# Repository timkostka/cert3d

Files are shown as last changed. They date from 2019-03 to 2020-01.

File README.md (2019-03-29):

# cert3d

Is your 3d printer firmware certified?

# What is Cert3D?

Cert3D is a project designed to certify the performance of 3d printer firmware.  It works by sending test g-code to the printer and monitoring the output of stepper motors.

## Why is Cert3D?

Within the 3d printer firmware community, there is a lack of verification of software features.  A massive amount of man-hours is spent on tracking down bugs which could otherwise be detected automatically.  The aim of this project is to enable developers to ensure features are working as intended before releasing software.

## Who benefits?

For developers, the testing framework helps identify bugs quickly allowing them to be fixed quickly.  The improved software quality due to this benefits.

## How does it work?

There are two parts to Cert3D--A hardware module and a software program.

### The hardware module

The hardware module is hooked up to the 3d printer board and monitors status of the stepper motors and other peripherals.

### The software program

The software sends runs a series of tests by sending g-code to the 3d printer board.  During these tests, it also reads back information from the hardware module.  It analyses these results to ensure the printer is working as intended.

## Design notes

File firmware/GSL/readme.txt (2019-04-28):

The GSL are Generic STM32F4 Libraries for various peripherals.  This is an
additional abstraction layer that makes use of the STM32 HAL libraries in a
way that is hopefully easier and more straightforward to use.

The GSL are header-only C++ libraries.  To use them, simply include the
"gsl_includes.h" file from a C++ source file.

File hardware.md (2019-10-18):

# Cert3D Hardware module

This file is for laying out the requirements for the hardware module.

At high speed, we need to monitor the DIR and STEP lines on each stepper motor driver.

Number of stepper motors:

* X axis

* Y axis

* Z axis

* E (extruder) axis

* (maybe) E2 axis (second extruder)

In each motor takes 4 lines (2 lines with rising/falling for each).  If we use timers on the STM32F4, what does this look like?

With 2 DMAs with 8 streams each, we are limited to 16 DMA-based interrupt transfers.  This would be enough without E2, except that doesn't leave us any for other functions, such as a UART debug stream.

Another option would be to set triggers to both rising and falling, and then detect the state in an interrupt or something.  This is more prone to error, but would probably work.

Another option would be to eliminate DMA-based triggers and do it in software via interrupts.

## What timing is necessary?

Looking at the DRV8825 driver, the required timing on a pulse on the STEP or DIR lines is 1.9us.  There is also a 650ns setup time between DIR rising/falling and STEP rising.  It would be nice to be able to verify that timing.

With an STM32F4 clock speed of 180MHz, we can run some timers at 180 MHz, and some others at 90MHz.  At 90MHz, this gives a timer period of 11.1 ns.  That seems good enough.

## Plan forward

Two timer channels per extruder seems fine, with one hooked up to STEP and the other to DIR.  If we plan for a single extruder, this is a total of 8 timer channels, and 8 DMA streams.

Can we use only high speed (APB2) timers for these?  These are TIM1 and TIM8-11.  Yes, both TIM1 and TIM8 have 4 available input channels.  Actually, the DMA streams overlap, so this would only allow us 6 DMA requests.  Let's just set it up with TIM1 only for now and work out the details later.  We may have to use 6 channels on high speed timers and 2 channels on slower timers.

### Results

I managed to get this working just fine using the TIM1 timer in IC mode for two channels at once.  Easily extensible to 4.  Resoltion of 1 timer tick at 160 MHz.  The output is written via DMA to a circular buffer.  I can easily parse this to capture individual edges.

What resolution should results be stored as?  If i use uint32_t and a tick of 180 MHz, this will overflow around 24sec.  So I could use uint64_t instead, although it's a bit clunky.  If I convert to float, then I lose some resolution.

Another option is to output only the delta between pulses.  I could use a uint16_t, and use 0 to indicate that there was no change for 2^16 ticks.  That is way more memory efficient.  2^16 ticks at 180MHz is 0.4ms, which is a bit low.  So maybe use uint32_t to reduce the number of zeros.

### Plotting results

Results should be output in a variety of modes.  One of those should be an oscilloscope-type mode where edges are shown.  This may be fun to develop.

## Hardware pins

What is actually needed to monitor/simulate a 3d printer board?

* (8 high-speed pins, 4 slower pins) Monitor X, Y, Z, and E stepper motors
  * Per motor, need STEP and DIR hooked up to timer IC inputs.  Can monitor EN with a slower GPIO pin.
* (1 pin) Stepper motor monitoring
* (3 pins) X, Y, and Z end-stops
* (2 pins) SWD interface
* (2 pins) UART debug input/output
* (1 pin) Error-indicating LED
* (1 pin) monitor bed heating on/off
* (3 pins) monitor fans?
* (2 DAC pins) simulate bed and hot end thermistors
* (1 pin) monitor hot end heater on/off
* (1 pin) simulate EZABL type bed leveler

### How to simulate a thermistor?

The common thermistors used in 3D printers are 100kOhm at room temp and go lower than this as they heat up, becoming as low as 220 Ohm at 150C.

A 100kOhm digital potentiometer might work well.

On the board (Duet 2 Wifi), thermistors are connected in the following circuit:

```
                         [3.3V]
                           |
                     [4.7kOhm 0.1%]
                           | 
MCU PIN>---+---[100kOhm]---+---[THERMISTOR]---+
           |                                 |
           = [2.2uF]                         |
           |                                 |
          GND                               GND
```

So the voltage on the thermistor shouldn't go over 2.24V.  If shorted, the current through it will be 0.7mA.

There are a few issues with using digipots for this.  First, the tolerance is awful, typically 20-30% and quite nonlinear.  Second, the number of taps is limited.  With 256 taps, the resistance increment would be 39 Ohm.  This is the difference between 225C and 265C.

One option would be using two digipots in series to get better resolution.  If we had a 100kOhm and a 1kOhm in series.  But 1kOhm are expensive.  No good solution that I can see.

For the bed, a digipot is probably fine.

I could use a DAC.  The STM32F4 has a 12-bit DAC.  This gives a resolution of 0.8 mV.  This is way better.  This may vary depending on how boards are set up, but it's doable.

With 2 DACs, we can simualte 2 thermistors.

### STEP/DIR channels

What channels and DMA streams can we use for the STEP/DIR signal monitoring?

* TIM1_CH1 - DMA2 Stream 1

* TIM1_CH2 - DMA2 Stream 2

* TIM1_CH3 - DMA2 Stream 6

* TIM1_CH4 - DMA2 Stream 4

* TIM8_CH1 - DMA2 Stream 2

* TIM8_CH2 - DMA2 Stream 3

* TIM8_CH3 - DMA2 Stream 4

* TIM8_CH4 - DMA2 Stream 7

So out of these, we can have 6 enabled.  These can monitor X, Y and E.  All channel on TIM1 and channels 2 and 4 on TIM8.

We need 2 more slow speed channels to monitor Z.

* TIM3_CH1 - DMA1 Stream 4

* TIM3_CH2 - DMA1 Stream 5

### Timer triggering

We need to start all timers at the same time in order to get relative timing correct between channels.  We can do this by setting up TIM3 and TIM8 in slave mode that trigger off of TIM1_TRGO signal.  For TIM3, this is the ITR0 trigger per Table 98 in RM90.  For TIM8, this is also ITRO0 per Table 94.

We want all timers to be in sync so that CNT register values are identical between them.  We can do this by triggering them to start at the same time.  I set up TIM1 in master mode and had TIM3 and TIM8 trigger off of it.  Doing this, there was a delay of 18-20 ticks between TIM1 and TIM8.  In other words, `TIM1->CNT = TIM8->CNT + (18 to 20)`.  This isn't desirable.

Can I use a different timer to trigger TIM1, TIM3 and TIM8 all at the same time?  The delay between the trigger and the timer starting should be the same for all three.

* TIM1 can be triggered from TIM5 (ITR0), TIM2 (ITR1), TIM3 (ITR2), and TIM4 (ITR3)
* TIM3 can be triggered from TIM1 (ITR0), TIM2 (ITR1), TIM5 (ITR2), and TIM4 (ITR3)
* TIM8 can be triggered from TIM1 (ITR0), TIM2 (ITR1), TIM4 (ITR2), and TIM5 (ITR3)

So yes, we can use TIM2 to trigger the other three.  Conveniently, they all use the same ITR1 signal to do so.  I did this and the timers appear to be perfectly in sync.  I got a difference of 8 ticks if I read them in one direction and -8 ticks if I reversed the order that I read them.  So probably exactly the same.

### Signal buffers

We need a buffer to store the timer CNT values at each edge change.  How large should this buffer be?  Our high speed timers reset at `65536/168MHz=2.5kHz`.  We want to process values at at least twice this rate in order to correctly interpret their CNT value.

Step rates for 3d printers (taken from https://reprap.org/wiki/Step_rates) top out at around 180kHz for 3 motors.  For a single motor, this is an edge generation rate of 360kHz.  Each edge needs 2 bytes.  If we process at 5kHz, then the buffer needs to be at least `360kHz * 2 byte / (5kHz) = 144 bytes`.  That's extremely small.  No problem.

Three motors running at 180kHz will produce 6 edges at 180kHz, which will create 8.64Mpbs of data.  This is too much to handle, but we could probably handle about half of that.  It's very unlikely to be running three motors this fast.

#### Buffer monitor callback

The buffers will be monitored by a callback at a frequency of around 5kHz.  On each pass, we need to monitor the signal lines and pass along information about any edges detected.

I clearly need an output buffer, where information goes when it's ready to be sent out.  The USB will read directly from this buffer when it is sending information.  This is the same way the debug log operates.

Maybe I need a staging buffer for each signal line where I translate the data so it's ready for output.  When these staging buffers get full enough, I can send out their info to the output buffer.  That seems good.

#### Output buffer

The output buffer information will be organized as follows:

The buffer will be primary in `uint16_t` format, occasionally putting two `uint8_t` values into a single `uint16_t`.

* Sync word at beginning `0x0B77`

* Channel number as a `uint16_t`

* Size of the of entries as a `uint16_t`

* Each entry as a single `uint16_t`

This structure repeats as necessary for each channel.

For signal channels, the `uint16_t` data entry represents the number of ticks between edges.  If the number of ticks is more than 65535, we encode it instead as a `uint16_t` of 0, then a `uint32_t` of the number of ticks.

On second thought, this requires us to do more calculations on the mcu.  I'd rather move processing of data to the computer.

#### Output processing try #2

We keep the output buffer.  However, a packet is sent on every processing step.  Each packet has the following info:

* Sync word `0x0B77`

* Packet number as `uint16_t`, first is 0, increments 1 each time, eventually flows over.

* For each signal channel (number of channels is known)

  * Number of entries as a `uint16_t` in channel `N`
  
  * Entry #1
  
  * Entry #2
  
  * etc...

The entries are the `TIMx->CNT` values.  Post-processing is done on the computer side to get the number of ticks between edges.

The computer can also detect missed packets (if any) since the packet number is included.

If no edges are detected, each packet is `2 + 2 + 8 * 2 = 20` bytes.  At a packet rate of 5kHz, this comes to 0.8 Mbps.  That's a bit much for purely overhead.

#### Output processing try #3

The primary drawback of the #2 method is that 0.8 Mbps is a lot for overhead.  We'll try to reduce that.  We also will reduce the amount we send the sync word since the connection shouldn't be lossy.

* (Only if packet number % 8 == 0) Sync word `0x77`

* Packet number as `uint8_t`, first is 0, increments 1 each time, eventually flows over.

* Single `uint8_t` value with mask showing which signal channels are present in this channel
  * If LSB (bit 0) is set, then channel 0 is present
  * If bit 1 is set, channel 1 is present
  * Etc...

* For each signal channel which is present (per the mask above)

  * Number of entries for this channel as a `uint8_t`
  
    * Note that we shouldn't need more than this per packet since `5kHz * 255 = 1.3 MHz`.  Channels shouldn't trigger that often.
  
  * (uint16_t) Entry #1
  
  * (uint16_t) Entry #2
  
  * etc...

* (uint8_t) Number of ADC samples present (typically 0 or 1)

* ADC samples as 14 packed 12-bit values (21 bytes per value)

Assuming no activity on the signal channels, and no ADC samples, this packet will be 3.125 bytes on average, which is 0.125 Mbps.  Much better.

### ADC triggering

We should also set up the ADC to trigger off a timer in order to keep relative timing correct, although the rate of ADC triggers should be pretty slow in order to keep bandwidth reasonable.

I did this.  The ADC triggers off of `TIM2_TRGO` signal.  Maybe I should move it somewhere else so I can independently adjust the frequency of samples?  The only options for the are TIM1, TIM2, TIM3, and TIM8.  I'm keeping TIM1 and TIM8 for their high speed edge detection, so TIM2 will have to trigger the ADCs.  And rev1 hardware has TIM3 reserved as well.  So I'm stuck with TIM2.  Can I get the other three to trigger off of a different timer?  Yes, they can all be triggered off of TIM4.  I did this.

### ADC sampling

How many samples should I take?

The ADC clock can run at a max of 36MHz.  If we have a system clock of 168 MHz and an APB2 clock of 84 MHz, we need to use a prescaler of 4, which gives us an ADC clock of 21 MHz.

It takes 15 clocks to convert a reading into a value.  This is in addition to the sampling time.

Say we wanted a reading on every channel at 10kHz.  With 14 channels, each sample needs to be done at 140kHz.  At a clock of 21MHz, this gives us 150 clocks per sample.  So we could choose the `ADC_SAMPLETIME_112CYCLES` sample time.  That seems fine.

At this rate, we would be generating `14 * 10kHz * 12 bit = 1.68Mbps`.  That still seems a bit high.  Let's sample at 1kHz to start.

### UART debug channel

This channel is used as a debug stream.

* USART3_RX - DMA1 Stream 1

* USART3_TX - DMA1 Stream 3

### Monitoring of on/off channels

There are a number of items we need to monitor for on/off.  Off, they should be pulled down to 0V.  On, they are set anywhere from 3.3V to 24V.  One option would be to use ADC channels to monitor the exact voltage for each of these channels.  If I used DMA, this works well to keep the timing between samples consistent.

If I expect voltages up to around 24V, the following circuit works well:

```
<ADC PIN>---+---[7.5kOhm]---<PRINTER PIN>
            |
            +---[1.0kOhm]---<GND>
```

With a 12-bit ADC, this gives a resolution of 6.8mV and a max voltage of 28.05V.  Since this will typically be used to monitor on/off peripherals, this seems fine.

### Ender3 thermistors

On the Ender3, thermistors are connected as follows:

```
          <5.0V>
            |
        [100kOhm]
            | 
<MCU PIN>---+---[THERMISTOR]---+
            |                  |
            = [2.2uF]          |
            |                  |
           GND                GND
```

### Simulating thermistor channels

We are using a DAC to simulate the thermistor.  I would like to protect it from being connected to 24V while still being able to simulate very high temperatures.

The BAT54C has a max power dissipation of 200mW.  At 24V, this is produced with a current of 8.3mA.  An inline resistor of 2.9 kOhm would prevent more than this.  However, this would prevent me from simulating very high temperatures.  No good.

Let's consider the following circuit diagram:

```
                          +---[R1=4.7kOhm]---<VH=3.3V>
                          |
<V1=DAC PIN>---+---[R3]---+---[R2=100kOhm]---<V2=PRINTER ADC PIN>
```

We can solve this for V2(V1, VH, R1, R2, R3):

```
I1 = (VH - V4) / R1
I2 = (V2 - V4) / R2 = 0
I3 = (V1 - V4) / R3
I1 + I2 + I3 = 0
--> V2 = (R1 * V1 + R3 * VH) / (R1 + R3)
```

The lowest this can go is with `V2(V1=0) = VH / (R1 / R3 + 1)`.  If I need to simulate a thermistor going as low as 200 Ohm, then I need the voltage to be `3.3V * 50 / (4700 + 40) = 0.135V`.  I could use an inline resistor of at most 200 Ohm to simulate this.

### Endstop simulating and detection

On the Ender3, the endstop pin is tied directly to the connector, and pulled up to VCC (5V) with a 10 kOhm resistor.

On the duet 2 wifi:

```
<3.3V>---[1kOhm]---[LED>|]---+
                             |
      <MCU PIN>---[10kOhm]---+---<ENDSTOP CONNECTOR>

```

In either case, we can simulate an endstop by using an open drain output and driving it to ground.  It needs to be protected from overvoltage.  A 100Ohm inline resistor would work fine, along with a diode clamp to the 3V3 rail.

### Figuring out STM32 USB drivers

After initializating, data is send via `CDC_Transmit_HS`.  This calls:

* `CDC_Transmit_HS`
  * `USBD_CDC_SetTxBuffer`
  * `USBD_CDC_TransmitPacket`
    * This checks for `TxState==0` else it returns busy.
    * `USBD_LL_Transmit`
      * `HAL_PCD_EP_Transmit`
        * `USB_EP0StartXfer`
        * `USB_EPStartXfer`

The `TxState` flag gets reset within `USBD_CDC_DataIn`.  Which is the `DataIn` member of.  Which gets called via `USBD_LL_DataInStage`.  Which gets called via `HAL_PCD_DataInStageCallback`.  Which gets called via `HAL_PCD_IRQHandler`.  Which gets called via `OTG_HS_IRQHandler`.  Which is an interrupt in the IRQ table.

To get better (?) throughput, it's possible I could add code to the end of `HAL_PCD_IRQHandler` to send out data if data is ready and `TxState==0`.  This may result in minimal downtime of the USB bus.

#### Enabling DMA

DMA is enabled by setting `hpcd_USB_OTG_HS.Init.dma_enable = DISABLE;`.  However, more is needed.  Likely, STM32CUBEMX will generate the necessary code.

I was not able to get this working with v1.21 firmware.  Likely there is a bug.  I think I got it working with 1.24 firmware, but the rest of my library is not yet compatible with that.  For now, I'll just stick with non-DMA version.

#### USB buffer

There will be a large buffer allocated to the outgoing USB buffer which we will call the staging buffer.  This staging buffer will be split into 2048-byte chunks.  Note this is the largest buffer we can send at a time through USB.

When we stage data, it will write to the current chunk.  If data flows over, then it will move to the next chunk, and so on.  If we ever move to the chunk that is currently being sent, this is an overflow condition.

Within the main loop, if the USB is inactive, we shall send out the next chunk, if possible.  If this chunk is not yet full, we will disable new information from being added and instead make it added to the next chunk.

We should have at least 50kB of buffer to devote to this.

#### How does receiving data work?

The `CDC_Receive_HS` function is called from within the IRQ handler.  Within this function, we call `USBD_CDC_SetRxBuffer` and `USBD_CDC_ReceivePacket` and then return `USBD_OK`.  If we don't call these function and instead just return `USBD_OK`, no more packets are received, as if the packet never gets registered as received.

The `USBD_CDC_SetRxBuffer` function just sets a buffer pointer.  No magic there.

The `USBD_CDC_ReceivePacket` calls the following:

* `USBD_CDC_ReceivePacket`
  * `USBD_LL_PrepareReceive`
    * `HAL_PCD_EP_Receive`
      * `USB_EP0StartXfer`
      * `USB_EPStartXfer`
        * `USBx_OUTEP(ep->num)->DOEPCTL |= (USB_OTG_DOEPCTL_CNAK | USB_OTG_DOEPCTL_EPENA);`

This last line enables transfer on this endpoint.

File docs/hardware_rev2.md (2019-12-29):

# Hardware changes for rev2

This file is to brainstorm possible changes to make to the rev1 hardware to create rev2.

## Ground pins

I need to add ground pins to the PCB so I can hook up grounds between this board and the printer board.  A few male header pins to the GND signal should be enough.  Possibly have these far enough away from other pins to be able to alligator clip onto them.

## Encoder channels (invalid option, see later)

The firmware is too slow to postprocess motor position from STEP/DIR edges when they're going quickly.  One possible solution would be to use the encoder function within the timer to process this via hardware.  This would require one channel per encoder.

There are a total of 6 timers that have encoder functionality.  We currently use 3 of these to process edges.  It is probably possible for us to use the other 3 as encoders.  This would look like the following:

* TIM1: 4 channels used to monitor STEP/DIR edges
* TIM8: 2 channels used to mointor STEP/DIR edges
  * Other 2 channels have a DMA conflict with TIM1 channels
  * Possible I could 
* TIM3: 2 channels used to monitor STEP/DIR edges
  * Other 2 channels can possibly be used as well.

* TIM2: encoder for X motor
  * Currently used to trigger ADC conversions.
  * Not sure how to free this up.
* TIM4: encoder for Y motor
  * Currently used as master timer.  I could quickly switch this from master timer to encoder mode after triggering other timers.  It may miss a few steps but this likely wouldn't even matter.  It is also possible the encoder mode will also trigger other channels, in which case switching wouldn't be necessary.
* TIM5: encoder for Z motor
  * Currently used for SECNT timer, which is easily moved to another timer.

### Encoder waveforms.

The following wavedrom script explains how we want the timer encoder to work.  Note how `CNT` should update right after a rising edge on `STEP` depending on the polarity of `DIR` at the time of the rising edge.

```
{signal: [
  {name: 'STEP', wave: 'lpppplppplpp'},
  {name: 'DIR', wave: 'h....l...h..'},
  {},
  {name: 'CNT', wave: '222222222222', data: ['0', '1', '2', '3', '4', '4', '3', '2', '1', '1', '2', '3']}
]}
```

Example encoder waveform

I think this can work using encoder mode 1:
```
001: Encoder mode 1 - Counter counts up/down on TI1FP1 edge depending on TI2FP2 level.
```

I would hook up `STEP` to `TI2` and `DIR` to `TI1`.

Actually, this doesn't work.  It looks like the timer changes value on both rising and falling edges, like a traditional encoder.  Hmm...

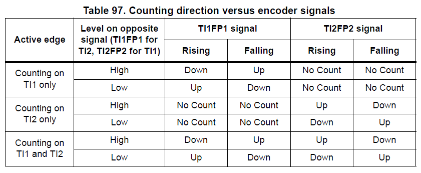
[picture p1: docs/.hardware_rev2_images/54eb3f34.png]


## Encoder channels

What other way can we get motor position from processing STEP/DIR pins via hardware?  With unlimited timers, I can think of several ways, but we have limited timers.

I could add another chip to the board and dedicate that to handling this.  This complicates board layout, firmware, debugging, etc.  Not an attractive option.

This is only needed to simulate endstops.  I could simply only simulate endstops when necessary.  For example, when doing a homing operation.  Travel speeds during homing should be nowhere near the max speed.  I would expect speeds of under 20mm/s.  At 80 step/mm, this would be 1600 steps/s, which is very doable in software.

## HRTIM usage

It is possible to use the HRTIM to capture up to 5 channels at 480MHz, but we need to capture 10 channels.

## STM32H7 microprocessor

We will switch to a 480 MHz STM32H745 microprocessor, which runs a 480 MHz M7 core and a 240 MHz M4 core.

To start, we will only use the M7 core.  Perhaps the M4 core can act do the endstops.

### USB connectivity

The bandwidth of FS HSB (up to 12Mbps) is probably fine.  I would like to get higher, but it would involve adding an external PHY.

### ADCs

Same as before, we'll add pins to read ADCs.  The ADC will be 16 bit.  TIM8 will triggert the ADCs.  Transfer from ADC to memory will use 1 DMA stream.

## Programmer

I'll use the ST-Link V3 Mini programmer with the standard 14-pin adapter.

## Protection resistors

I'm going to remove all protection diodes/resistors.  This is just a development board, we can add them back on later.  They just make building it a bit harder and more space intensive.

## Timer channels

I'm not going to use the HRTIM.  Instead, I'll use the standard timers at 240 MHz, or maybe 200 MHz.  I need 10 channels, but I'll add 12:
* TIM1_CH1-4
* TIM2_CH1-4
* TIM3_CH1-4

Each of these channels uses a DMA stream.

Maybe HRTIM can be used as a high-speed timer between events?  If not, I'll use use TIM4/TIM5.

## Debug stream

The M7 core will send the debug stream to USART1 via DMA.  No debug stream on the M4 core, for now.  This uses 1-2 DMA channels, depending if we want input as well as output.

## Debug pins

I will have a number of pins used for debug purposes only.  Probably 4 is enough, but maybe 8 would be better.

## Endstop pins

Ideally, we will have 12 GPIO inputs for end stop pins.

## DMA streams

There are 16 DMA streams available which will be used as follows:
* (12) Input channels
* (2) USART debug stream
* (1) ADC transfer to memory

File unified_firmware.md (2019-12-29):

# Unified firmware

This file contains info about using the same firmware for both cores on an STM32H745 chip.

## Core detection

A core can be detected by looking at the `SCB->CPUID` register.  Bits [15:4] hold the part number, which will bewhich will be 0xC27 for a CM7 core and 0xC24 for a CM4 core. 

We can test for this immediately within the ResetHandler using assembly language
```
Reset_Handler:
  /* set M4 stack pointer */
  ldr   sp, =_estack_cm4

  /* on M4 core, skip past initialization */
  ldr r2, =_scb_cpuid
  ldr r0, [r2]
  lsr r0, #4
  and r0, #0xF
  cmp r0, #4
  beq CoreM4

CoreM7:
  /* set M7 stack pointer */
  ldr   sp, =_estack_cm7
```

## Implementing printf

It would be nice to have printf implemented so that it can be used as a debug log.  However, there are some issues:
* Increase in code size by ~20kB
  * This is generally not a problem as we have the space
* printf calls malloc
  * This goes against our desire to have no dynamically allocated memory
* Some implementations are not thread-safe
  * For a dual-core device, this can be a problem if they are part of the same compilation unit, which is the goal of the unified firmware.

One option would be to implement printf.  This project does it:
* https://github.com/mpaland/printf

I took this last option which seems to be working well.  To use it, one needs to include `printf.h` prior to using any `printf` calls.

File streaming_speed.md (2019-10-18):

# Streaming speed

This file is intended to figure out how much data needs to be sent across the USB interface.

## Methodology

It is required that all timers update at the same frequency.  However, they can have different individual tick frequencies.

For each timer update, a single packet should be sent to the computer with the ADC values and the timer count at each detected edge.  This packet will have the

## Header packet

Before streaming data, a header packet must be sent to the computer which holds the format of the streamed data.  This header has the following format:

* `char[9] start_string`
  * The string `InfoStart` to denote the start of this packet.
* `uint8_t header_packet_version`
  * Streaming data packet version number.
  * The version of the format given here is 1.
* `uint8_t streaming_packet_version`
  * Streaming data packet version number.
* `uint32_t system_clock`
  * System clock tick speed in Hz.
* `uint8_t signal_channel_count`
  * Number of signal channels in the packet.
* `uint8_t adc_channel_count`
  * Number of ADC channels in the packet.
* `uint32_t ticks_per_adc_reading`
  * Number of system ticks between ADC readings.
* For each signal channel:
  * `uint32_t signal_clock`
    * Clock tick speed in Hz of this channel.
  * `uint32_t update_ticks`
    * Number of ticks per timer update 
* For each ADC signal:
  * `float zero_value`
    * Voltage value corresponding to a zero count value on the channel.
  * `float high_value`
    * Voltage value corresponding to a max count (4095) on this channel.
* `char[8] end_string`
  * The string `InfoStop` to denote the start of this packet.

## Data packet

A data packet is sent for each update.  This data packet is sent at a frequency of `clock / ticks_per_update`.  This data packet version is 1.

* `uint8_t packet_number`
  * Incremental counter for the packet number
  * First is 0, second is 1, etc...
* `uint8_t channel_mask`
  * Mask showing which signal channels are present in this channel
    * If LSB (bit 0) is set, then channel 0 is present
    * If bit 1 is set, channel 1 is present
    * Etc...
* For each signal channel which is present (per the mask above)
  * `uint8_t edge_count`
    * Number of entries for this channel
  * For each edge:
    * `uint16_t timer_edge`
      * Value of timer at this edge.
* `uint8_t adc_sample_count`
  * Number of ADC samples present (typically 0 or 1)
* For each ADC sample:
  * For each ADC channel:
    * `uint16_t adc_value`
      * Raw value of the ADC of this channel

## Timer update

We set a primary timer that triggers at a rate of `2 * clock / ticks_per_update`.  This is tied to a callback routine.  In this routine, we do the following:

## Timer settings

Here are the timer settings from the previous firmware version:
```
[00.341359] Timers detailed description:
[00.345363] - Total timers defined: 14
[00.349194] TIM1, clock enabled
[00.352375] - SMCR: TS=011 SMS=110
[00.356014] - DIER: CC4DE=1 CC3DE=1 CC2DE=1 CC1DE=1
[00.361345] - SR: UIF=1
[00.363806] - CCMR1: OC2M=001 IC2F=0001 CC2S=01 OC1M=001 IC1F=0001 CC1S=01
[00.371675] - CCMR2: OC4M=001 IC4F=0001 CC4S=01 OC3M=001 IC3F=0001 CC3S=01
[00.379544] - CCER: CC4NP=1 CC4P=1 CC4E=1 CC3NP=1 CC3P=1 CC3E=1 CC2NP=1 CC2P=1 CC2E=1 CC1NP=1 CC1P=1 CC1E=1
[00.390768] - ARR: ARR=65535
[00.393706] TIM2, clock enabled
[00.396886] - CR2: MMS=010
[00.399660] - SMCR: MSM=1 TS=011 SMS=110
[00.403941] - SR: UIF=1
[00.406402] - PSC: PSC=9
[00.408950] - ARR: ARR=8399
[00.411793] TIM3, clock enabled
[00.414974] - SMCR: TS=011 SMS=110
[00.418614] - DIER: CC2DE=1 CC1DE=1
[00.422280] - SR: UIF=1
[00.424741] - CCMR1: OC2M=001 IC2F=0001 CC2S=01 OC1M=001 IC1F=0001 CC1S=01
[00.432611] - CCER: CC2NP=1 CC2P=1 CC2E=1 CC1NP=1 CC1P=1 CC1E=1
[00.439223] - ARR: ARR=32767
[00.442161] TIM4, clock enabled
[00.445342] - DIER: UIE=1
[00.447994] - ARR: ARR=65535
[00.450932] TIM5, clock enabled
[00.454112] - CR1: CEN=1
[00.456660] - DIER: UIE=1
[00.459313] - CNT: CNT=3872
[00.462155] - PSC: PSC=9999
[00.464998] - ARR: ARR=8399
[00.467840] TIM8, clock enabled
[00.471021] - SMCR: TS=010 SMS=110
[00.474661] - DIER: CC4DE=1 CC2DE=1
[00.478336] - SR: UIF=1
[00.480797] - CCMR1: OC2M=001 IC2F=0001 CC2S=01
[00.485780] - CCMR2: OC4M=001 IC4F=0001 CC4S=01
[00.490764] - CCER: CC4NP=1 CC4P=1 CC4E=1 CC2NP=1 CC2P=1 CC2E=1
[00.497376] - ARR: ARR=65535
```

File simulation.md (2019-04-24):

# Motivation

After some observations of Marling and RepRap, it is clearly a nontrivial task to convet STEP/DIR readings into accurate POS/VEL/ACC curves, especially the last two.  Because of the quantized nature of stepping, there needs to be something to smooth out the process.  In the actual printer, this is achieved by mechanical means--inertia of the head and motors, etc.

With that thought, maybe it would be best to simulate the equation of motion to postprocess VEL/ACC curves from the STEP/DIR curves?  What would this look like?  What does the system look like?

Let's consider a simpified system:

* The hot end has some inertial mass.

* The belt act as a stiff spring.

* The stepper motor acts as another stiff spring.

* Damping between the hot end and the bar it's on.

The mechanics of the stepper motor are complicated--the current through the windings is very dynamic and nontrivial to simulate.  At a first cut, we will ignore this.  Maybe the mass of the hot end dominates the system.

The system of equations is a simple mass-damper system.  Let `x` be the position of the hot end, `e` be the position given by `STEP`/`DIR`, `k` be the stiffness of the belt and stepper motor, and `c` be the damping in the system.  Then our equation of motion is:

* `m x" + (x' - e') * c + (x - e) * k == 0`

where " means d/dt^2 and ' means d/dt.  We can simplify this to:

`m * x" + c * x' + k * x == c* e' + k * e`

What should the constants be?

* The mass is maybe 100g.

* The stiffness for the stepper motor will vary based on the max torque of the stepper.

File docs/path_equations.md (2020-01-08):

# Path equations

This contains a reference for different types of paths

## Constant velocity

With a constant velocity of v0, the position vs time is given as:

* x(t) = x0 + v0 * t
* v(t) = v0

## Constant acceleration

* x(t) = x0 + v0 * t + 1/2 * a0 * t^2
* v(t) = v0 + a0 * t
* a(t) = a0

## Constant jerk

* x(t) = x0 + v0 * t + 1/2 * a0 * t^2 + 1/6 * j0 * t^3
* v(t) = v0 + a0 * t + 1/2 * j0 * t^2
* a(t) = a0 + j0 * t
* j(t) = j0

An equation for speeding up smoothly from 0 to to vf with a max jerk of j0 would be:

At the transition from j(t) = j0 to j(t) = -j0, we should be at half of the final speed, which lets us solve for the time of this transition:
* v(tt) = 1/2 * j0 * tt^2 = 1/2 * vf
* --> tt = sqrt(vf / j0)

Before this transition:
* x(t) = 1/6 * j0 * t^3
* v(t) = 1/2 * j0 * t^2
* a(t) = j0 * t
* j(t) = j0

At transition (t = tt):
* x(tt) = 1/6 * vf^1.5 * j0^-0.5
* v(tt) = 1/2 * vf
* a(tt) = vf^0.5 * j0^0.5

From tt <= t <= 2 * tt, we have j(t) = -j0
* x(t) = 1/6 * vf^1.5 * j0^-0.5 + 1/2 * vf * (t - tt) + 1/2 * vf^0.5 * j0^0.5 * (t - tt)^2 - 1/6 * j0 * (t - tt)^3
* v(t) = 1/2 * vf + vf^0.5 * j0^0.5 * (t - tt) - 1/2 * j0 * (t - tt)^2
* a(t) = vf^0.5 * j0^0.5 - j0 * (t - tt)
* j(t) = -j0

At t = 2 * tt. we have:
* x(t) = vf^1.5 * j0^-0.5
* v(t) = vf
* a(t) = 0
Which matches up with our expectations on the final velocity and acceleration.

Suppose we want to traverse a 90 degree angle by using this trajectory.  For 0 < t < tt, we would have
* x(t) = 1/6 * j0 * t^3 (accelerating from v0=0)
* vx(t) = 1/2 * j0 * t^2
* y(t) = vf * t - 1/6 * j0 * t^3 (decelerating from v0 = vf)
* vy(t) = vf - 1/2 * j0 * t^2
* s(t) = sqrt(vx(t)^2 + vy(t)^2)
* s(t) = sqrt((1/2 * j0 * t^2)^2 + (vf - 1/2 * j0 * t^2)^2)
* s(t) = sqrt(1/4 * j0^2 * t^4 + vf^2 + 1/4 * j0^2 * t^4 - vf * j0 * t^2)
* s(t) = sqrt(vf^2 - (j0 * t^2) * (vf - 1/2 * j0 * t^2))

At the transition (t=tt) the speed is:
* s(tt) = vf^2 / sqrt(2)

The speed is minimized halfway through the transition.  This distance from the corner is maximized at this time as well.

## Constant jerk with max accel

With initial velocity v0, max accel amax, max jerk jmax:

Within d1 segment:
* x(t) = v0 * t + 1 / 6 * jmax * t^3

At t = d1 (Note that d1 = amax / jmax):
* x(t = d1) = v0 * d1 + 1 / 6 * jmax * d1^3
* x'(t = d1) = v0 + 1 / 2 * jmax * d1^2

For d1 < t < d1 + d2:
* x(t) = (v0 + 1 / 2 * amax * d1 ^ 2) * (t - d1) + 1/2 * amax * (t - d1)^2
* x'(t) = (v0 + 1 / 2 * amax * d1 ^ 2) + amax * (t - d1)

At t = d1 + d2 (Note that d1 = amax / jmax):
* x(t = d1 + d2) = (v0 + 1 / 2 * amax * d1) * d2 + 1/2 * amax * d2^2
* x'(t = d1 + d2) = v0 + 1 / 2 * amax * d1 + amax * d2

For d1 + d2 < t < d1 + d2 + d3:
* x(t) = x'(t = d1 + d2) * (t - d1 - d2) - 1/6 * jmax * (t - d1 - d2)^3
* x'(t) = x'(t = d1 + d2) - 1/2 * jmax * (t - d1 - d2)^2

At t = d1 + d2 + d3:
* x(t = d1 + d2 + d3) = (v0 + 1/2 * amax * d1 + amax * d2) * d3 - 1/6 * jmax * d3 ^ 3
* x'(t = d1 + d2 + d3) = v0 + 1/2 * amax * d1 + amax * d2 - 1/2 * jmax * d3^2

Note that we must have d1 = d3.  We need to find d2 such that x(d1 + d2 + d3) meets the target distance.  This is easy:
* d2 = (dist - v0 * d1 - 1/2 * amax * d1^2 + 1/6 * jmax * d1 ^ 3) / (amax * d1)

## Nominal/starting values to for jerk

This section tries to find reasonable values for the jerk setting.  Note that many 3d printer controllers implement a change of velocity of around 10 mm/s which seems extreme but the printer handles it okay.

Say we want a printing speed of 40 mm/s and we want the printer to ramp up from rest to this max speed within dx = 2mm.  From our equations before:
* x(tf) = vf^1.5 * j0^-0.5 = dx
* --> j0 = vf^3 / dx^2

For our values in the previous paragraph, this translates to a max jerk of j0 = 16000 mm/s^3.  It also translates to a max acceleration of:
* a(tf / 2) = vf^0.5 * j0^0.5 = 800 mm/s^2

This is a reasonable max acceleration value.  I was okay using values around 2000-4000mm/s^2 when printing items and it worked okay.

With these settings, it will take 100ms to ramp from zero to 40 mm/s.

## Path segments

Path segments should be easy to calculate.  We will assume a constant jerk within each segment.  So each segment can look like:

```
strict PathSegment {
  float duration;
  float t0;
  float x0;
  float v0;
  float a0;
  float j0;
}
```

The planner will have a way to calculate the current time, so calculating the position and velocity will be easy:
* x(t) = x0 + v0 * t + 1/2 * a0 * t^2 + 1/6 * j0 * t^3
* v(t) = v0 + a0 * t + 1/2 * j0 * t^2

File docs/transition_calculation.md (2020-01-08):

# Transition calculation

Within our path planner, we wish to move from one line segment to another line segment in such a way that we do not actually touch the corner, but rather smoothly transition from one segment to the next.  This has the advantage of having less of a jarring impact on the printer which results in better print quality.

## Problem statement

The problem we are trying to solve can be simplified as this:

* Assume we are moving on the line from point `p0` to point `p1` with velocity `vs`.
* We want to end up moving on the line from point `p1` to point `p2` with velocity `vf` such that `||vf|| == ||vs||`.
* We begin and end the transition a distance `d` away from point `p1`.
* The net velocity change `dv` is in the direction away from the corner at an angle that bisects the two paths.

The transition distance `d` must be minimized subject to the following constraints:
* The maximum acceleration `amax` cannot exceed `alimit`.
* The maximum jerk `j` cannot exceed `jlimit`.

Note that the velocity during the transition is slower than at the entry/exit points, so no additional limit on the velocity is necessary.



## Types of paths

There are two nontrivial types of paths in this scenario.  In one, the acceleration curve is a triangle and the maximum acceleration does not exceed `alimit`.  In the second type, the acceleration is a trapezoid profile.  In both, the slope on the diagonal lines in the profile is equal to `jlimit`.

## Calculations

Consider the above figure.  We can easily rearrange whatever coordinate system we're working with such that it lines up with this figure.  The change in velocity is then only in the negative y direction, and the velocity in the x direction does not change.

Let the initial speed be `s = ||vs||`.

We can decompose the initial velocity into its x and y components: `vs = vx*ex + vy*ey`.  Note that `vy = s * cos(theta / 2)` and `vx = s * sin(theta / 2)`.  The total distance we're traveling in the x direction is equal to `dx = 2 * d * sin(theta / 2)`.  Since `vx` doesn't change during the transition, the total time it takes to traverse this distance is `dt = dx / vx`.

Note that `dv = -2 * vy * ey`.

If our path is the first type, the maximum acceleration we hit is `amax = dt / 2 * jlimit`.  If this is greater than `alimit`, then our path must be the second type.  Otherwise, we must have `vy = dt / 2 * dt / 2 * jlimit`.  This gives us the final equation to solve.

If our path is the second type, the duration spent ramping to max on each side is `tramp = alimit / jlimit`.  The time spent at max accel must then be equal to `tflat = dt - 2 * tramp`.  The total velocity change must be `2 * vy = tramp * tramp * jlimit + alimit * tflat`.  This gives us the final equation to solve.

## Path type one

The knowns are angle `theta` and initial speed `s`.

Our equations to solve are:
* `vy = s * cos(theta / 2)`
* `vx = s * sin(theta / 2)`
* `dx = 2 * d * sin(theta / 2)`
* `dt = dx / vx`
* `vy = 0.125 * jlimit * dt^2`

We can solve these to find:
* `--> d = s * sqrt(2 * s * cos(theta / 2) / jlimit)`

## Path type two

The knowns are angle `theta` and initial speed `s`.

Our equations to solve are:
* `vy = s * cos(theta / 2)` --> vy is known
* `vx = s * sin(theta / 2)` --> vx is known
* `dx = 2 * d * sin(theta / 2)` --> d(dx) or dx(d)
* `dt = dx / vx`
* `tramp = alimit / jlimit` --> tramp is known
* `dt = 2 * tramp + tflat`
* `2 * vy = tramp * tramp * jlimit + alimit * tflat`
* `2 * vy = alimit * (tramp + tflat)`

Solve to find:
* `2 * s * cos(theta / 2) / alimit = tramp + tflat`
* `2 * s * cos(theta / 2) / alimit + alimit / jlimit = 2 * d * sin(theta / 2) / (s * sin(theta / 2))`
* `--> d = s^2 * cos(theta / 2) / alimit + 0.5 * s * alimit / jlimit`

## Straight line path

For motion in a straight line, assuming we always want to travel as fast as possible, we have the following generic path type:

generic straight path

Some of these durations may be zero.  For example, if the initial velocity is already at max, `d1 = d2 = d3 = 0`.

We need to create a routine that takes initial speed, final speed, and path distance and calculates the durations for each of these.

Note that we have some symmetry between durations.  In particular, we must have `d1 = d3` and `d4 = d6`.

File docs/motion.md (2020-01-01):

# Simulating the equations of motion

By monitoring the STEP and DIR signals, we know the target position of each motor.  This signal is discontinuous wich a jump occuring at every pulse of the STEP signal.  Since the derivative of this signal is infinite, we must use some other way to estimate the velocity of the motor.

This document looks at methods for deriving the position, velocity, and acceleration from the interpreted STEP/DIR signals.

## Equation of motion

We know the motor can't move instantly, so let's apply a force to the motor to make it move to its target position.

The force will be similar to the keeping force on a steppet motor.  It will be proportional to the difference between the target and actual position.  A damping force will also be present.

If the current position is x(t) and the target position is x_t(t), the equation of motion looks like the following:

* x"(t) = k * (x_t(t) - x(t)) - c * x'(t)
* v'(t) = k * (x_t(t) - x(t)) - c * v(t)

This equation can be solved even if x_t(t) is discontinuous.

We can solve this with the implicit midpoint method.

Let dt be the timestep.

* v_n+1 = v_n + dt * v'(t + dt / 2, (v_n + v_n+1) / 2)
* v_n+1 = v_n + dt * (k * (x_t(t + dt/2) - (x_n + v_n * dt / 2)) - c * ((v_n + v_n+1) / 2))

* v_n+1 = v_n + dt * k * x_t(t + dt/2) - dt * k * (x_n + v_n * dt / 2) - dt * c * v_n / 2 - dt * c * v_n+1 / 2
* v_n+1 * (1 + dt * c / 2) = v_n * (1 - dt * c / 2) + dt * k * x_t(t + dt/2) - dt * k * (x_n + v_n * dt / 2)

This works pretty well in Excel.

## Physical constants

We should ground our equation in reality.  We need to find values for m, k and c that make sense:

* m x" = k * x - c * x'

If we let x be the position of the nozzle, then m should be the weight of the hot end.  For direct drive printers, the hot end often has a NEMA 42-40 stepper motor on it.

Some NEMA 17 motors are listed here: https://reprap.org/wiki/NEMA_17_Stepper_motor

We will assume the following specs for the motor:
* 1.8 degree step angle
* 40 N*cm holding torque
* 370 grams (measured)

The stiffness translates to about 40 N*cm per 1.8 degrees.  This torque moves a belt over a pulley of diameter 0.7" (measured).  The pulley has 20 teeth and the belt has 1 tooth per 2mm, so the effective pulley diameter should be D = (40mm / pi). So this translates into a linear stiffness of 40 N*m / (40mm/2pi) / (1.8deg / 360deg * 40mm) = 180,000 lbf/in.  Seems a little high.

We will assume a mass of 150grams, which is probably about right for an Ender 3. 

This yields a natural frequency of sqrt(k/m) = 460 Hz.  This seems in the right ballpark.

We will calculate c based on the perceived damping ratio.  Based on ripples in the print after a 90 degree turn, the oscillations disappear after about 3-5 oscillations.  This gives us a damping ratio of around 0.2.

The unknowns k, c, m can be reduced to just the natural frequency (omega_n) and the damping ratio (zeta).  In these variables, the equation of motion above is equivalent to:
* x" = omega_n^2 * x - 2 * zeta * omega_n * x'

## In practice

I put together a script (equations_of_motion.py) which solves these equations of motion.  With omega_n = 500 Hz and zeta = 0.15, the position looked very reasonable.
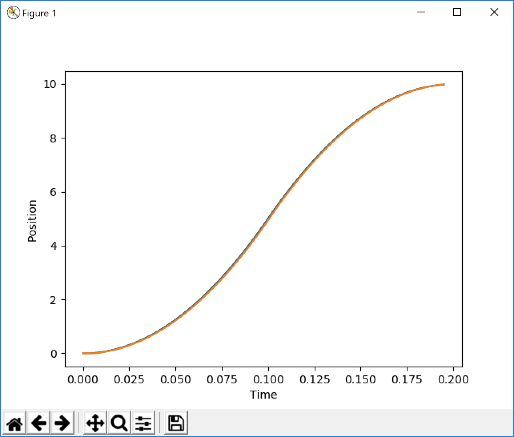
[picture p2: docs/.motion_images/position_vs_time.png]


However, the acceleration was still all over the place.
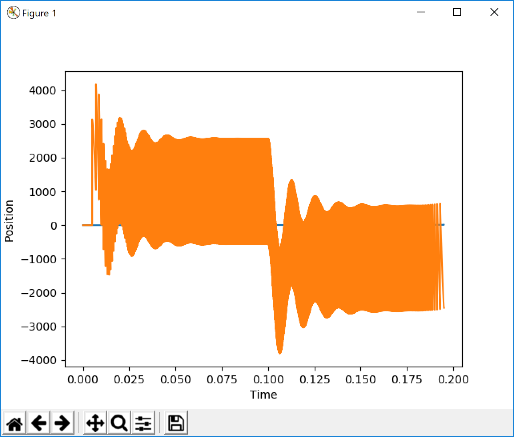
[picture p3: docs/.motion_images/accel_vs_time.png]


Zooming in, I can see the acceleration jumps whenever a STEP comes in
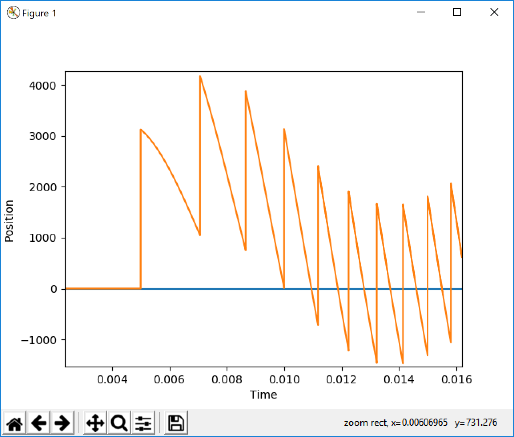
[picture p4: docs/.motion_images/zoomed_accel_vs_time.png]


There's no way to avoid this with the parameters I have without significantly lowering the natural frequency of the system.  This may be similar to the actual behavior in real-life, as the printer emits a sound at the frequency of the STEP pulses.  However, it is undesirable for these high frequencies to show up in the simulated equations of motion.

To counteract this, I will first simulate the position of the stepper motor itself and then use this to simulate the position of the hot end.

## Equation derivations

To derive the equation of motion, we start with

* m * x"(t) = k * (x_t(t) - x(t)) - c * x'(t)
* m * v'(t) = k * (x_t(t) - x(t)) - c * v(t)

where v(t) is the velocity of the hot end, x(t) is the position of the hot end and x_t(t) is the position of the stepper motor (known).  We assume constant v' within a timestep.

* v'(t) = omega_n^2 * (xt(t) - x(t)) - 2 * zeta * omega_n * v(t)
* v'(t) = f(t, v(t), x(t))

Within a timestep, we know:

* x(t0 + dt) = x(t0) + dt * v(t0) + 1/2 * dt^2 * v'(t) 
* x_n+1 = x_n + dt * (v_n + v_n+1) / 2

Let v_n = v(t) and v_n+1 = v(t + dt).  Using the implicit midpoint method:

* v_n+1 = v_n + dt * f(t_n + dt / 2, 1/2 * (v_n + v_n+1), 1/2 * (x_n + x_n+1))

Substituting values gives us (Let on = omega_n, z = zeta):

* f(...) = omega_n^2 * (1/2 * (xt_n + xt_n+1) - 1/2 * (x_n + x_n+1)) - 2 * zeta * omega_n * 1/2 * (v_n + v_n+1)
* f(...) = omega_n^2 * (1/2 * (xt_n + xt_n+1) - 1/2 * (x_n + (x_n + dt * (v_n + v_n+1) / 2))) - 2 * zeta * omega_n * 1/2 * (v_n + v_n+1)
* f(...) = 1/2 * on^2 * (xt_n + xt_n+1) - 1/2 * on^2 * (2 * x_n + dt * (v_n + v_n+1) / 2) - z * on * v_n - z * on * v_n+1
* f(...) = 1/2 * on^2 * (xt_n + xt_n+1) + (-(on^2)) * x_n + (-1/4 * on^2 * dt) * v_n + (-1/4 * on^2 * dt) * v_n+1 - z * on * v_n - z * on * v_n+1
* f(...) = 1/2 * on^2 * (xt_n + xt_n+1) - on^2 * x_n - v_n * (1/4 * on^2 * dt + z * on) - v_n+1 * (z * on + 1/4 * on^2 * dt)

Our update then becomes:
* v_n+1 = v_n + dt * 1/2 * on^2 * (xt_n + xt_n+1) - dt * on^2 * x_n - dt * v_n * (1/4 * on^2 * dt + z * on) - dt * v_n+1 * (z * on + 1/4 * on^2 * dt)
* --> v_n+1 = (v_n + dt * 1/2 * on^2 * (xt_n + xt_n+1) - dt * on^2 * x_n - dt * v_n * (1/4 * on^2 * dt + z * on)) / (1 + dt * z * on + 1/4 * dt^2 * on^2)
* (and) --> x_n+1 = x_n + dt * (v_n + v_n+1) / 2



## Stepper motor behavior

Here is one page that discusses response to a single step input:
* https://www.orientalmotor.com/stepper-motors/technology/stepper-motor-overview.html

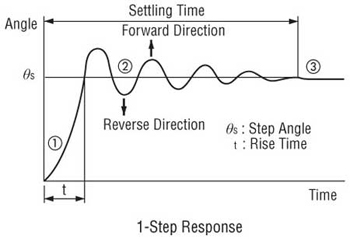
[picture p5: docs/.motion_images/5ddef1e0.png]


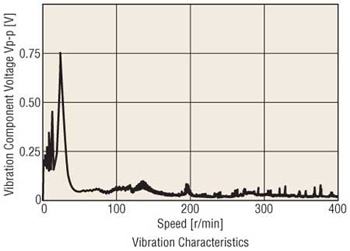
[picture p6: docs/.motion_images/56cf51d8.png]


The vibration plot is interesting.  Here is a video on it:

* https://www.youtube.com/watch?v=Rv8NVF6ZLlQ

## Dual method results

After simulating both the stepper and the hot end, the results are okay

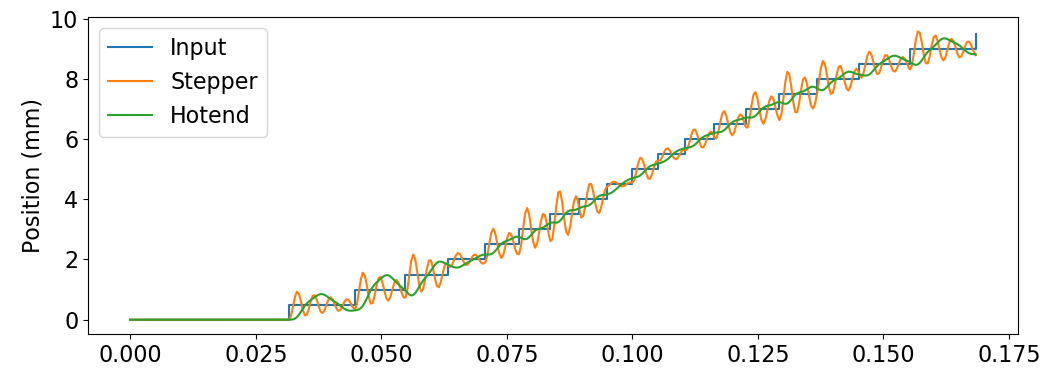
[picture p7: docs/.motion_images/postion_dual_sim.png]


However, the forces involved are pretty intense.

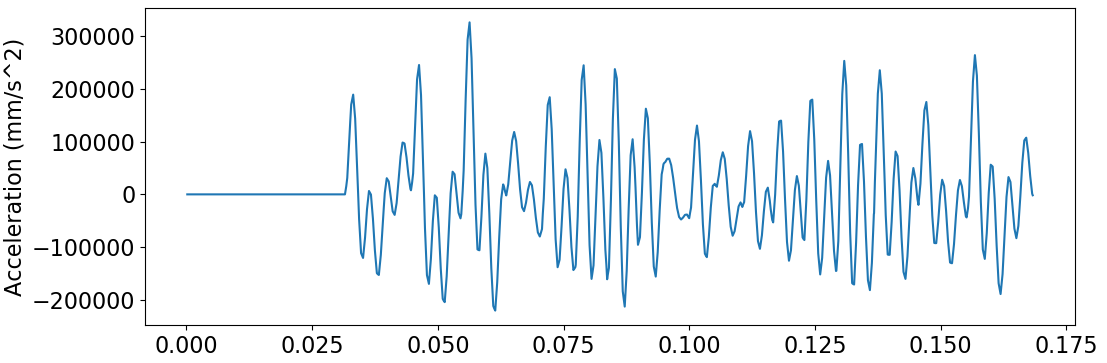
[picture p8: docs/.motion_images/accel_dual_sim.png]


A real stepper motor is going to have a top-end torque after which the force will roll off.  I should simulate the forces from the stepper motor better, and maybe simulate everything at once.  I will likely need to change the method away from the midpoint implicit method.

## Block method

The new method is to have simulate the hot end and the stepper motor position all at once.  To do so, we form a partial differendial equation (PDE) with the position and velocity of the stepper and hotend as variables.

### Stepper motor force

We will incorporate microstepping into the simulation.  The force from the stepper motor will be in the form of sine wave.  If x is the distance of the stepper away from its neutral position, x_s is the (full) step size of the motor, and F_max is the maximum force, the force from the stepper motor is

* F(x) = -F_max * sin(x / x_s * pi / 2)

Note that the motor achieves a maximum force a distance of x_s away from neutral.

Because of the inductance in the coils, the stepper cannot immediately switch phases.

This is still TBD.

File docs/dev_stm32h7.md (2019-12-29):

# Migration to STM32H7

I'd like to port this to the STM32H745/747 because it's faster (480MHz vs 168 MHz) and about as expensive.  The dual core nature also has interesting possibilities.

## ST-Link VCP connections

First thing to get up and running is a UART debug log functionality.

It would be nice to implement this so that `printf` functions get redirected to the debug log.  A lot of external libraries use `printf` for debug.

I have a STM32H747-DISCO board which I will use to prototype.  There is a nucleo board planned but it is not yet available on Mouser or Digikey.

On the board the PA9 (USART1_TX) and PA10 (USART1_RX) pins are connected to the ST-Link VCP.

I'll stick with 115200 8-E-1 protocol as this is supported by the UART bootloader and it's what I've been using on the STM32F4 line.

### Power supply

This board gets 3.3V power from the ST-Link USB connection via the JP3 jumper.  Voltage was measured and verified.

### Peripheral clocks

Per "9.5.10 Peripheral allocation" of the RM0399 reference manual, each core can allocate a peripheral for itself or for the other core.  I believe a core must activate the clock for itself before accessing it.

Accessing the `__HAL_RCC_USART1_CLK_ENABLE_()` macro which sets the `RCC_APB2ENR_USART1EN` bit will allocate the peripheral for the core that is currently executing that instruction.  The memory is remapped to make this possible.

### Implementing printf

It seems like to implement printf, I can implement the lower-level call `_write`.
* https://electronics.stackexchange.com/questions/206113/how-do-i-use-the-printf-function-on-stm32

### Input capture

It may be possible to use the HRTIM peripheral (480 MHz) to capture up to 10 input channels.

It looks like the CPT1DE/CPT2DE bits control the DMA request enable for each channel.  These use the hrtim_dmaX (X=2 to 6) channel.

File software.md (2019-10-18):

# Software package
# Software package

The software package part of Cert3D will be PC-based application.  It shall have the following features:

* Have USB interface to the Cert3D hardware board and be able to download information.

* (If possible) Interface with the printer directly to be able to send g codes and request status updates.

## File organization

* cert3d.py: this is the main file.

* ScopeResultsWindow.py: This file is generated by wxFormBuilder and is the layout of the window.

* ScopePanel.py: This is a custom widget to draw oscilloscope-type information on a panel.

* Channel.py: This hold information about a singl channel, either digital or analog.

* BilevelData.py: This holds data on a single channel of digital data.

* PlotData.py: This holds xy data on a single channel. 

### ScopePanel.py

This widget inherits from wx.Panel and nicely displays a number of channels on a form.  Data can either be bilevel or plot.

To add a channel, we use the `Add(data)` function where `data` is either (for now) `BilevelData` or `PlotData`.

#### Graphic layout

Channel names should be on the left-hand side of the widget.  Each channel can have a custom height, with the minimum height being the height of the channel name.

The width of the channel name display shall be fixed to the minimum possible size and recalculated when a new channel is added.

### ScopeChannel.py

This should hold aethestic information about the channel (color, height, scaling).  It will also do the drawing.

### Commands

The C3D board can be sent commands over USB.  The following are implemented:

* `start`
  * Begin streaming over the USB port.
* `stop`
  * Stop streaming data.
* `info`
  * Send the configuration packet over the USB port.  Streaming must be disabled.

#### Info packet

The information packet contains information on how to interpret data coming 
 over the USB.  Note that some configuration is done over the USB.

* `char[9] start_string`
  * The string `InfoStart` to denote the start of this packet.
* `uint32_t clock`
  * System clock speed.
* `uint8_t signal_channel_count`
  * Number of signal channels in the packet.
* `uint8_t adc_channel_count`
  * Number of ADC channels in the packet.
* For each signal channel:
  * `uint32_t clock`
    * Clock speed in Hz of this channel.
* For each ADC signal:
  * `float zero_value`
    * Voltage value corresponding to a zero count value on the channel.
  * `float high_value`
    * Voltage value corresponding to a max count (4095) on this channel.
* `char[8] end_string`
  * The string `InfoStop` to denote the start of this packet.

### TriStateData

I added a third signal type: `TriStateData`.  This is similar to the bilevel data, except it has a third state.  The third state will be high-z and will display as grayed out over the entire range.  The idea is to use this to simplify bilevel data with millions of points for zoomed out views.

#### Simplifying data

I expect to have massive data sets.  If a STEP channel for a motor triggers at ~100kHz, that is 200,000 data points per second.  One can see how this adds up.  Drawing all data set points would be prohibitve.

To simplify bilevel data, we can approximate it using a  

I also expect channels to be dormant for long periods of time.  In a zoomed out view, it would be nice to be able to see period of inactivity and activity.

Data sets will be simplified by augmenting the data set with one or more simplified sets.  These sets will have less points than the original and will be used when the data set is zoomed out.

##### How to simplify the data set?

Zoom value is a ticks/pixel value.

1. Look at the original data set.  If it has less than X (maybe 1000?) edges, do not simplify.  Else, continue.

2. Find the level of zoom at which we have no more than X (maybe 1000) edges per X (maybe asize(2000)?) pixels.  This is our maximum zoom.

3. Find the level of zoom to fit the entire data set within X (maybe asize(2000)?) pixels.  This is our minimum zoom.

4. Add zoom levels between min and max such that the zoom value jumps by no more than a factor of X (maybe 2.0)?

At this point, we have all zoom levels we need to create, with the most zoomed in level equal to the original data set.

Better idea:

1. Find the maximum zoom level as in (2) above.  Then, create a list of edge durations and sort it.  Collapse each duration less than double the median edge duration.  Calculate level of zoom for this new data set, and repeat until we have under 1000 edges in the set.  This should only repeat a few times.

The problem with this is the "collapse a duration."  Collapsing a single duration doesn't actuall achieve anything except reduce quality of the data set.  We need to collapse two durations to reduce the number of edges.  With that in mind, here is an improved algorithm:

1. Find the maximum zoom level as in (2) above.

2. Create a list of double edge durations (i.e. the duration between edge 0 and edge 2, edge 1 and edge, 3, edge 2 and edge 4, etc...).  Take twice the median of this list.  Collapse all durations which are less than this value.

3. Note that collapsing a duration means setting the value from 0 or 1 to 2, and combining adjacent durations of value 2.

This works really well.  I implemented it within a `DataCluster` object for now.

### Object achitecture

We have a lot of different objects which are all related.  Maybe we can get rid of some and make the heirarchy flatter?  Maybe we can eliminate or consolidate some `*Data` types?

Where should all these objects live, in terms of files?

Here is our current file/object heirarchy:

* File `AnalysisWindowBase.py`
  * Object `AnalysisWindowBase`
  * (Auto-generated from wxFormBuilder)
* File `cert3d.py`
  * Object `AnalysisWindow` which inherits from `AnalysisWindowBase`
    * Inherits from `AnalysisWindowBase` 
* File `ScopePanel.py`
  * Object `ScopePanel` which inherits from `wx.Panel`
* File `ScopeChannel.py`
  * Object `Signal`
  * Object `ScopeChannel`
* File `dpi.py`
  * Contains methods for working with high (and low) DPI displays.
* File `BilevelData.py`
  * Object `DataCluster`
  * Object `BilevelData`
  * Object `TriStateData`
* File `PlotData.py`
  * Object `PlotData`

Here is our window object heirarchy

* Object `AnalysisWindow`
  * Many standard objects like buttons, which are not listed here
  * Object `ScopePanel`
    * Many visual properties like zoom state, channel length, etc.
    * Time offset of start of display (in seconds)
    * Zoom state (in pixels per second)
    * Many `ScopeChannel` objects
      * channel height
      * (if necessary as for `PlotData`), value at bottom and top
      * Each can have many `Signal` objects
        * name of signal
        * color of signal
        * thickness of signal
        * reference to active data
        * function to select active data given a zoom factor
        * `DataCluster` object with min zoom state and data objects

I think I should eliminate the `DataCluster` object and turn it into a property of a `Signal`.

Here's what a `Signal` could look like:

* Object `Signal`
  * property `name` for name of signal, displayed on left of the channel
  * property `color` of type `wx.Colour`
  * property `thickness` for thickness in pixels of the signal drawn
  * property `active_data` which points to the active data based on zoom level of type (`BilevelData`, `TriStateData`, or `PlotData`)
  * property `data_cluster` which is a list of (`min_zoom`, `data`)
    * property `min_zoom` is the minimum zoom at which this data can be active
    * property `data` is a data of type (`BilevelData`, `TriStateData`, or `PlotData`)
  * function `draw_signal` which draws the signal on a rectangle
    * parameter `wx.DC`
    * parameter `wx.Rectangle`
    * parameter `pixels_per_second`
    * parameter `start_time` which is the time at the very left of the rectangle
    * parameter `value_range` which is the value at the bottom and top of the rectangle.  Only used for data of type `PlotData`.

The `Signal` object should have the following:

* Parameter `start_time` for the start of the data time
* Function `get_length()` which returns the length of the data

Each `*Data` type should have the following parameters/functions:

* Parameter `points` which holds the data points in a format used only by itself.
* Parameter `start_time` for the start of the data time
* Function `get_edge_near_time(time)` which returns the time of the edge closest to the given time.

I did this, it seems way better.  The `cert3d.py` file is a little busy, but workable.

### Slave thread instructions

The slave thread is necessary because the buffers for the USB data on both the STM32 side and the computer side are small.  In order to maximize throughput, the port needs to be read out very quickly.  The slave this does this without any interruption from other things such as UI redrawing.  Even with the PIL, this works well since most of the waiting is IO based.

The master thread needs to communicate with the slave.  It does so through some global variables.

The master thread should be able to know when the slave thread has crashed.  It can do so with this `Thread.is_alive` function.

Here are some instructions we need to implement:

* Open USB port (or don't)
* Start or stop logging to file, or read but ignore data
  * File is only open when logging is active
* Exit thread

### Postprocessing data

Once we have the `STEP` and `DIR` channels, we need to estimate the position, velocity and acceleration of the channel.  This is a nontrivial exercise.

* To calculate `POS`, assume each active edge on `STEP` is immediate.

* After `POS` is calculated, post-process it by looking for regions of large idle time and add points to make the `POS` channel constant during the majority of these times.  Use an idle time of 1ms.
  * For example, if we have data points `(0.0 s, 0)`, `(1.0 s, 1)`, add a point at `(0.999s, 0)`.

* Calculate `VEL` as the sum of many triangular pulses, the area of each is the same and the duration is varied based on nearby points.  This may be tuned.

  * We need a way to calculate (x, y) points from a bunch of triangular pulses.

  * Put pulses in a list sorted by the endtime.

  * I did this.  It works okay.

* Calculate `ACC` as the exact derivative of `VEL`.  Since VEL is piecewise linear, ACC is piecewise constant.

  * This produces some artifacts, which are real but undesired.  One way to remove these would be to apply a slew rate control to the signal.

### Saving g-code tests

In the Test Runner window, I need a method for saving many different tests.  I'll have a combo box populated with the name of each test along with a Save and Delete buttons.  They will be saved in the LOCALAPPDATA folder in the `tests.py` file in the following format:

```
test["basic_accel"] = ["G1 X0", "G1 X1"]
...
```

I can then use `exec` to read these back in.

I implemented this.  It's nice.

### Simplifying PlotData data

We need a way to create a simplified data set of out PlotData.  Maybe we can have another Data type similar to PlotData, except it would have a range of values.  I have two ideas.

* For each interval, draw a rectangle with a stipple interior over the range of values it can have.  This has one downside in that if the data is towards one side of the range, that information is lost in translation.

* For each interval, find the mean value.  Draw a line connecting these mean values.  Also find the range of values and maybe draw a thick stippled line with this information.

After looking, there is a DrawPolygon function.  I'm sure this could be useful.

How can I calculate somewhat tight-fitting min and max value curves?

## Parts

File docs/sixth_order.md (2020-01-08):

TinyG implementes a third-order jerk equation within a velocity change.

Around a junction, we want to solve:
* x'(t) = 1 
* y(-1) = 1
* y(1) = 1
* y'(-1) = -1
* y'(1) = 1
* y''(-1) = 0
* y''(1) = 0
* y'''(t) = a*t^3 + b*t^2 + c*t + d

We can integrate to find:
* y''(t) = 1/4*a*t^4 + 1/3*b*t^3 + 1/2*c*t^2 + d*t + e
* y'(t) = 1/20*a*t^5 + 1/12*b*t^4 + 1/6*c*t^3 + 1/2*d*t^2 + e*t + f
* y(t) = 1/120*a*t^6 + 1/60*b*t^5 + 1/24*c*t^4 + 1/6*d*t^3 + 1/2*e*t^2 + f*t + g

And solve using Mathematica.

Here is a comparision between paths using constant accel (blue), constant jerk (black/orange), and sixth order (red):

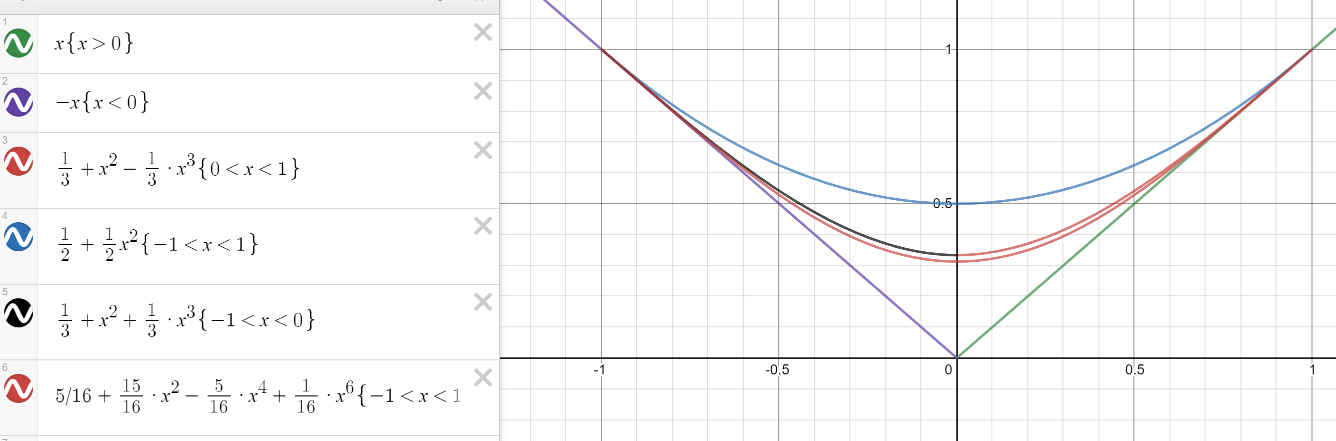
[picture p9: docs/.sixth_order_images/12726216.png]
path comparisons


There is very little difference between the constant jerk path and the sixth order path.  The constant jerk also has the ability to limit max acceleration, which the sixth order doesn't have.  Maybe this is a plus, maybe not.

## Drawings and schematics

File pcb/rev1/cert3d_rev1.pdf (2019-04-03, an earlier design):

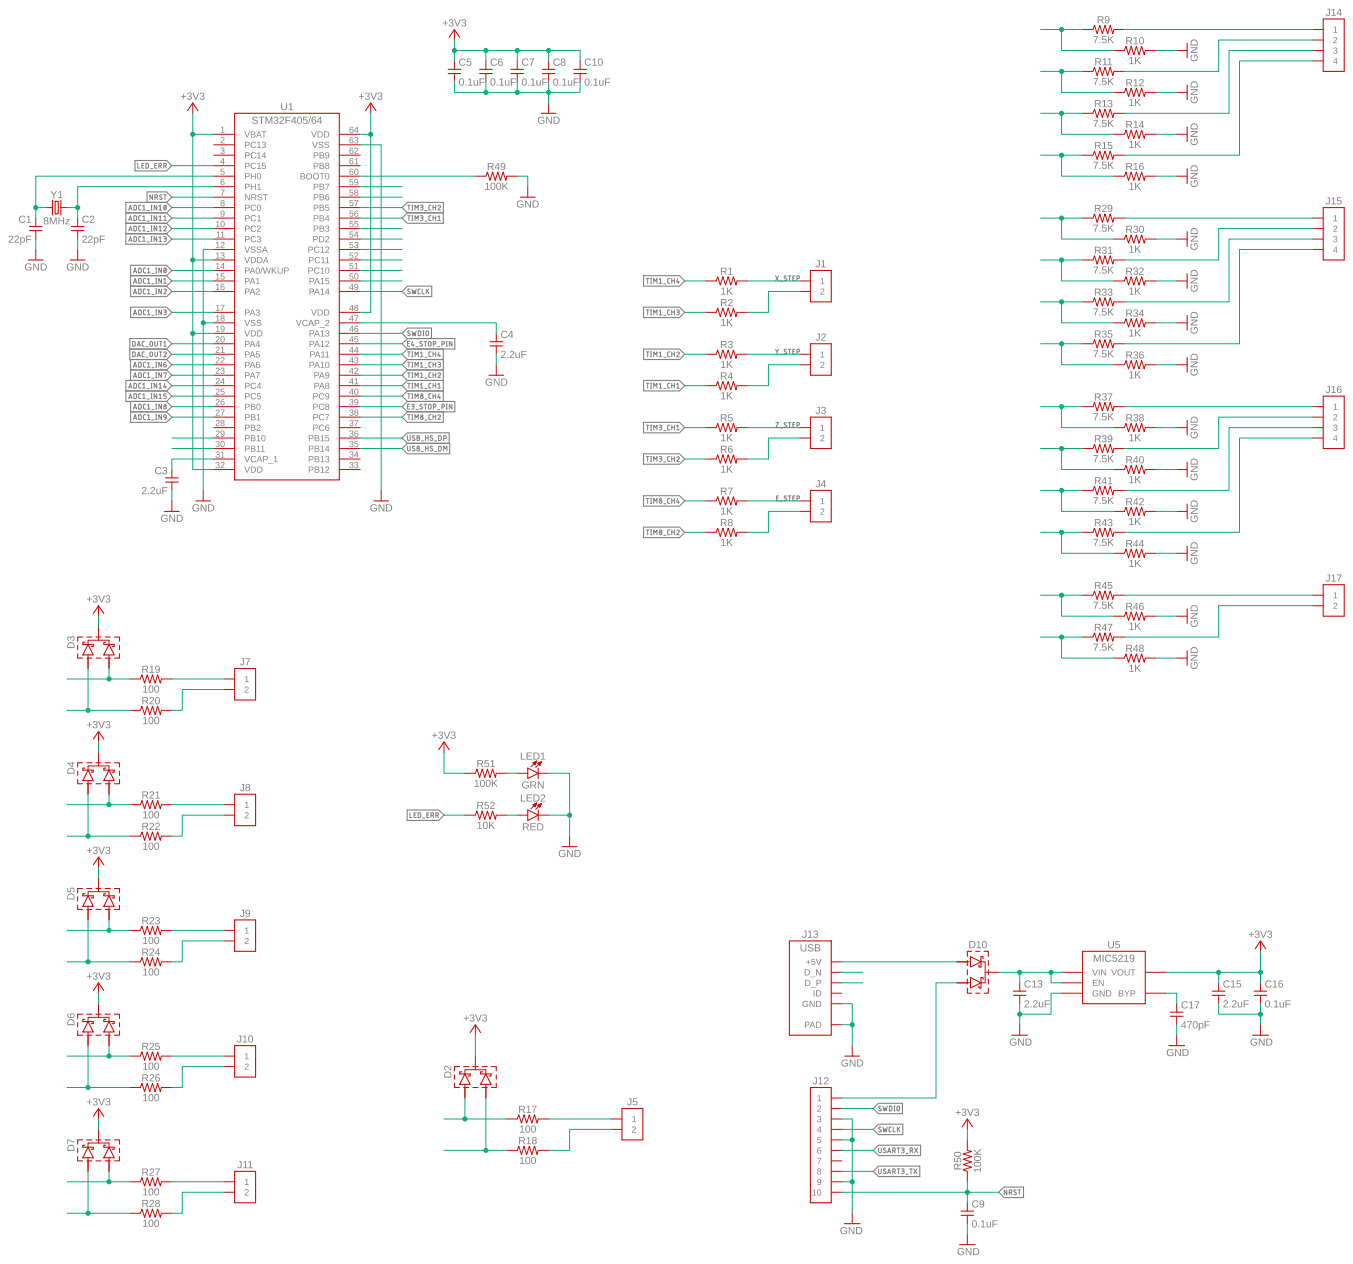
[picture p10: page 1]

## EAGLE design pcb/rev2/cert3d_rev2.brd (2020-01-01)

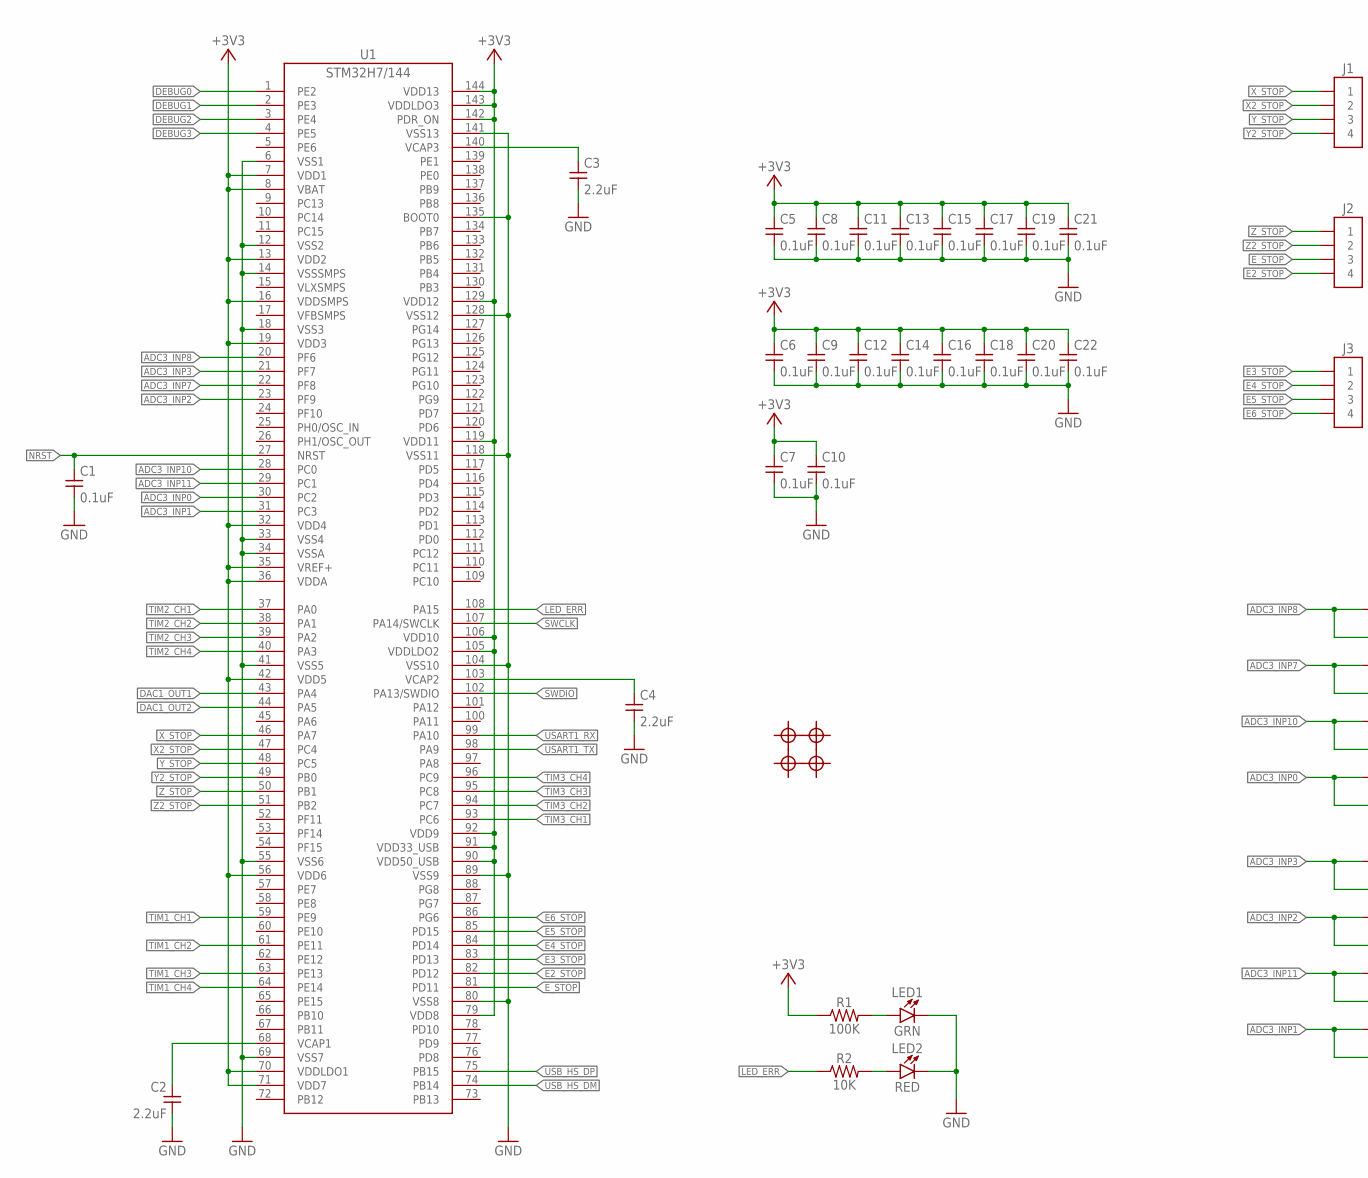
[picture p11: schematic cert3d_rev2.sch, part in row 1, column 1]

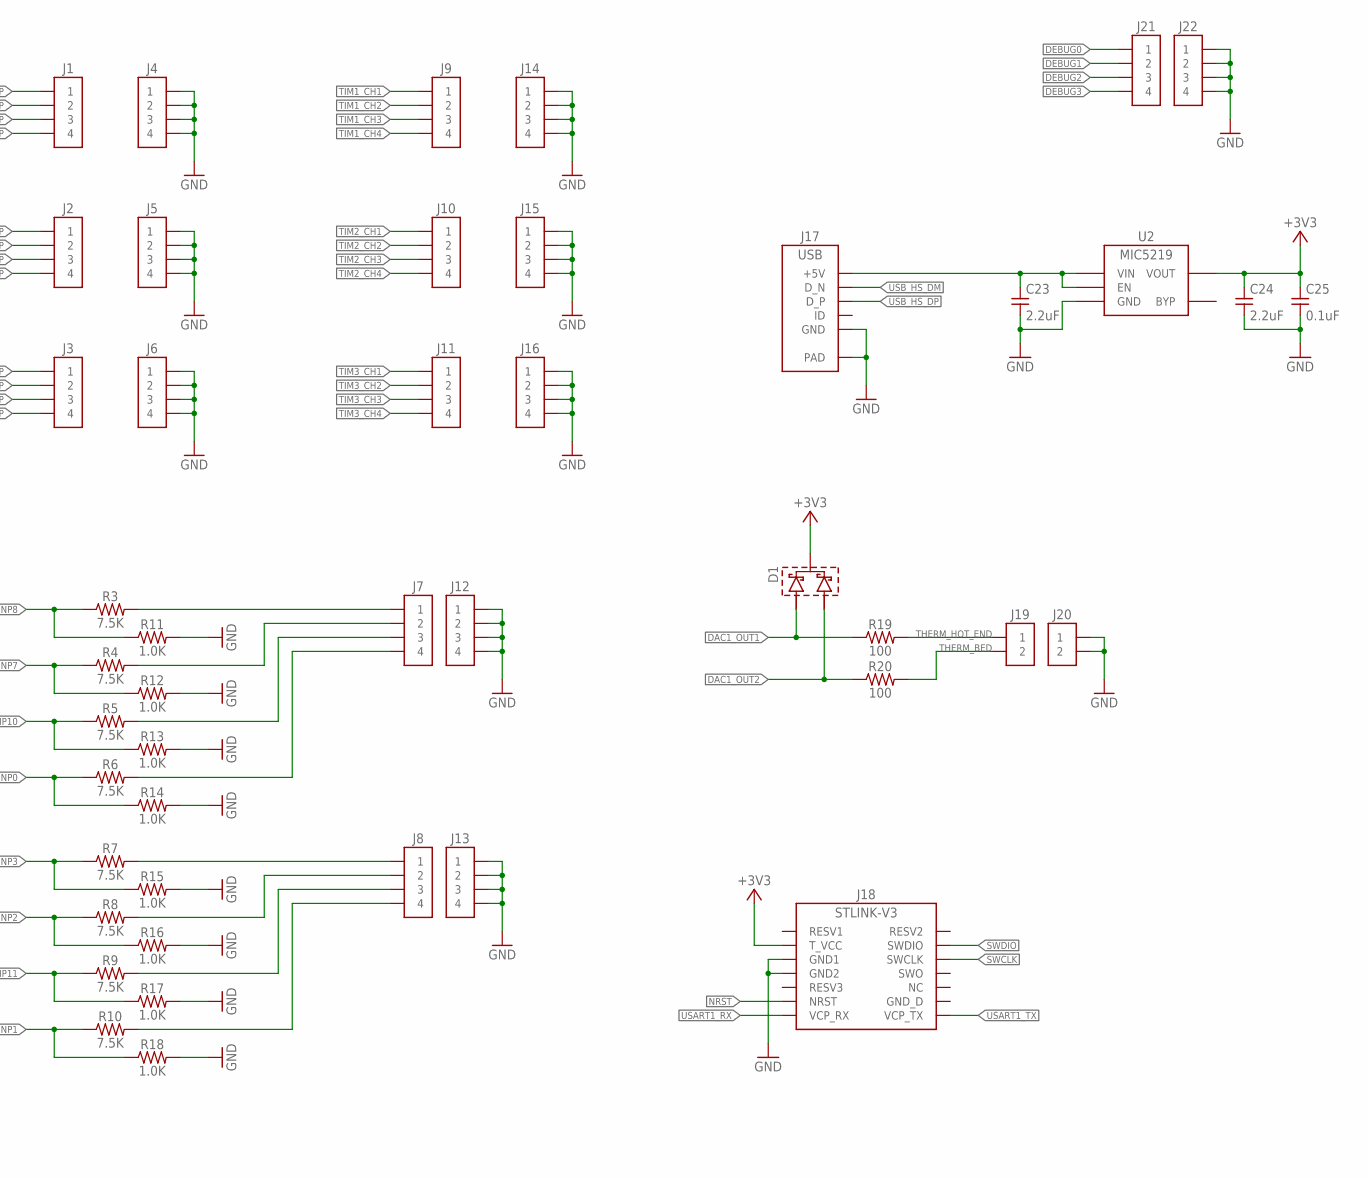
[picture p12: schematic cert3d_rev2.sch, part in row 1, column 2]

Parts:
C1, C5, C6, C7, C8, C9, C10, C11, C12, C13, C14, C15, C16, C17, C18, C19, C20, C21, C22, C25: 0.1uF; C0805-5MIL
C2, C3, C4, C23, C24: 2.2uF; C0805-5MIL
D1: SCHOTTKY_DUAL_CCBAT54C; SOT23-3
FD1, FD2, FD3, FD4: FIDUCIAL; FID1MM
J1, J2, J3, J4, J5, J6, J7, J8, J9, J10, J11, J12, J13, J14, J15, J16, J21, J22: CONN4TSW-S; SAM-TSW-104-XX-X-S
J17: USB-5PINTOPVIA; HIR-ZX62R-B-5P-VIAS
J18: STLINK-V3/SWDCNC-3220; CNC-3220-14-0100-00
J19, J20: CONN2TSW-S; SAM-TSW-102-XX-X-S
LED1: GRN; CHIPLED0805-SMALL
LED2: RED; CHIPLED0805-SMALL
R1: 100K; RES0805R-5MIL
R2: 10K; RES0805R-5MIL
R3, R4, R5, R6, R7, R8, R9, R10: 7.5K; RES0805R-5MIL
R11, R12, R13, R14, R15, R16, R17, R18: 1.0K; RES0805R-5MIL
R19, R20: 100; RES0805R-5MIL
U1: STM32H745-144; LQFP144-20X20MM
U2: MIC5219; SOT23-5

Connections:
+3V3: C5.1, C6.1, C7.1, C8.1, C9.1, C10.1, C11.1, C12.1, C13.1, C14.1, C15.1, C16.1, C17.1, C18.1, C19.1, C20.1, C21.1, C22.1, C24.1, C25.1, D1.3 (C), J18.3 (T_VCC), R1.1, U1.7 (VDD1), U1.8 (VBAT), U1.13 (VDD2), U1.16 (VDDSMPS), U1.19 (VDD3), U1.32 (VDD4), U1.35 (VREF+), U1.36 (VDDA), U1.42 (VDD5), U1.56 (VDD6), U1.70 (VDDLDO1), U1.71 (VDD7), U1.79 (VDD8), U1.90 (VDD50_USB), U1.91 (VDD33_USB), U1.92 (VDD9), U1.105 (VDDLDO2), U1.106 (VDD10), U1.119 (VDD11), U1.129 (VDD12), U1.142 (PDR_ON), U1.143 (VDDLDO3), U1.144 (VDD13), U2.5 (VOUT)
ADC3_INP0: R6.1, R14.1, U1.30 (PC2)
ADC3_INP1: R10.1, R18.1, U1.31 (PC3)
ADC3_INP2: R8.1, R16.1, U1.23 (PF9)
ADC3_INP3: R7.1, R15.1, U1.21 (PF7)
ADC3_INP7: R4.1, R12.1, U1.22 (PF8)
ADC3_INP8: R3.1, R11.1, U1.20 (PF6)
ADC3_INP10: R5.1, R13.1, U1.28 (PC0)
ADC3_INP11: R9.1, R17.1, U1.29 (PC1)
DAC1_OUT1: D1.1 (A1), R19.1, U1.43 (PA4)
DAC1_OUT2: D1.2 (A2), R20.1, U1.44 (PA5)
DEBUG0: J21.1, U1.1 (PE2)
DEBUG1: J21.2, U1.2 (PE3)
DEBUG2: J21.3, U1.3 (PE4)
DEBUG3: J21.4, U1.4 (PE5)
E2_STOP: J2.4, U1.82 (PD12)
E3_STOP: J3.1, U1.83 (PD13)
E4_STOP: J3.2, U1.84 (PD14)
E5_STOP: J3.3, U1.85 (PD15)
E6_STOP: J3.4, U1.86 (PG6)
E_STOP: J2.3, U1.81 (PD11)
GND: C1.2, C2.2, C3.2, C4.2, C5.2, C6.2, C7.2, C8.2, C9.2, C10.2, C11.2, C12.2, C13.2, C14.2, C15.2, C16.2, C17.2, C18.2, C19.2, C20.2, C21.2, C22.2, C23.2, C24.2, C25.2, J4.1, J4.2, J4.3, J4.4, J5.1, J5.2, J5.3, J5.4, J6.1, J6.2, J6.3, J6.4, J12.1, J12.2, J12.3, J12.4, J13.1, J13.2, J13.3, J13.4, J14.1, J14.2, J14.3, J14.4, J15.1, J15.2, J15.3, J15.4, J16.1, J16.2, J16.3, J16.4, J17.5 (GND), J17.PAD@1 (PAD), J17.PAD@2 (PAD), J17.PAD@3 (PAD), J17.PAD@4 (PAD), J17.PAD@5 (PAD), J17.PAD@6 (PAD), J17.PAD@7 (PAD), J17.PAD@8 (PAD), J17.PAD@9 (PAD), J17.PAD@10 (PAD), J17.PAD@11 (PAD), J17.PAD@12 (PAD), J18.5 (GND1), J18.7 (GND2), J20.1, J20.2, J22.1, J22.2, J22.3, J22.4, LED1.C, LED2.C, R11.2, R12.2, R13.2, R14.2, R15.2, R16.2, R17.2, R18.2, U1.6 (VSS1), U1.12 (VSS2), U1.14 (VSSSMPS), U1.18 (VSS3), U1.33 (VSS4), U1.34 (VSSA), U1.41 (VSS5), U1.55 (VSS6), U1.69 (VSS7), U1.80 (VSS8), U1.89 (VSS9), U1.104 (VSS10), U1.118 (VSS11), U1.128 (VSS12), U1.135 (BOOT0), U1.141 (VSS13), U2.2 (GND)
LED_ERR: R2.1, U1.108 (PA15)
unnamed: C2.1, U1.68 (VCAP1)
unnamed: C4.1, U1.103 (VCAP2)
unnamed: J7.3, R5.2
unnamed: J7.1, R3.2
unnamed: J8.2, R8.2
unnamed: J7.2, R4.2
unnamed: C3.1, U1.140 (VCAP3)
unnamed: C23.1, J17.1 (+5V), U2.1 (VIN), U2.3 (EN)
unnamed: J8.3, R9.2
unnamed: J7.4, R6.2
unnamed: J8.4, R10.2
unnamed: J8.1, R7.2
unnamed: LED2.A, R2.2
unnamed: LED1.A, R1.2
NRST: C1.1, J18.11 (NRST), U1.27 (NRST)
SWCLK: J18.6 (SWCLK), U1.107 (PA14/SWCLK)
SWDIO: J18.4 (SWDIO), U1.102 (PA13/SWDIO)
THERM_BED: J19.2, R20.2
THERM_HOT_END: J19.1, R19.2
TIM1_CH1: J9.1, U1.59 (PE9)
TIM1_CH2: J9.2, U1.61 (PE11)
TIM1_CH3: J9.3, U1.63 (PE13)
TIM1_CH4: J9.4, U1.64 (PE14)
TIM2_CH1: J10.1, U1.37 (PA0)
TIM2_CH2: J10.2, U1.38 (PA1)
TIM2_CH3: J10.3, U1.39 (PA2)
TIM2_CH4: J10.4, U1.40 (PA3)
TIM3_CH1: J11.1, U1.93 (PC6)
TIM3_CH2: J11.2, U1.94 (PC7)
TIM3_CH3: J11.3, U1.95 (PC8)
TIM3_CH4: J11.4, U1.96 (PC9)
USART1_RX: J18.13 (VCP_RX), U1.99 (PA10)
USART1_TX: J18.14 (VCP_TX), U1.98 (PA9)
USB_HS_DM: J17.2 (D_N), U1.74 (PB14)
USB_HS_DP: J17.3 (D_P), U1.75 (PB15)
X2_STOP: J1.2, U1.47 (PC4)
X_STOP: J1.1, U1.46 (PA7)
Y2_STOP: J1.4, U1.49 (PB0)
Y_STOP: J1.3, U1.48 (PC5)
Z2_STOP: J2.2, U1.51 (PB2)
Z_STOP: J2.1, U1.50 (PB1)

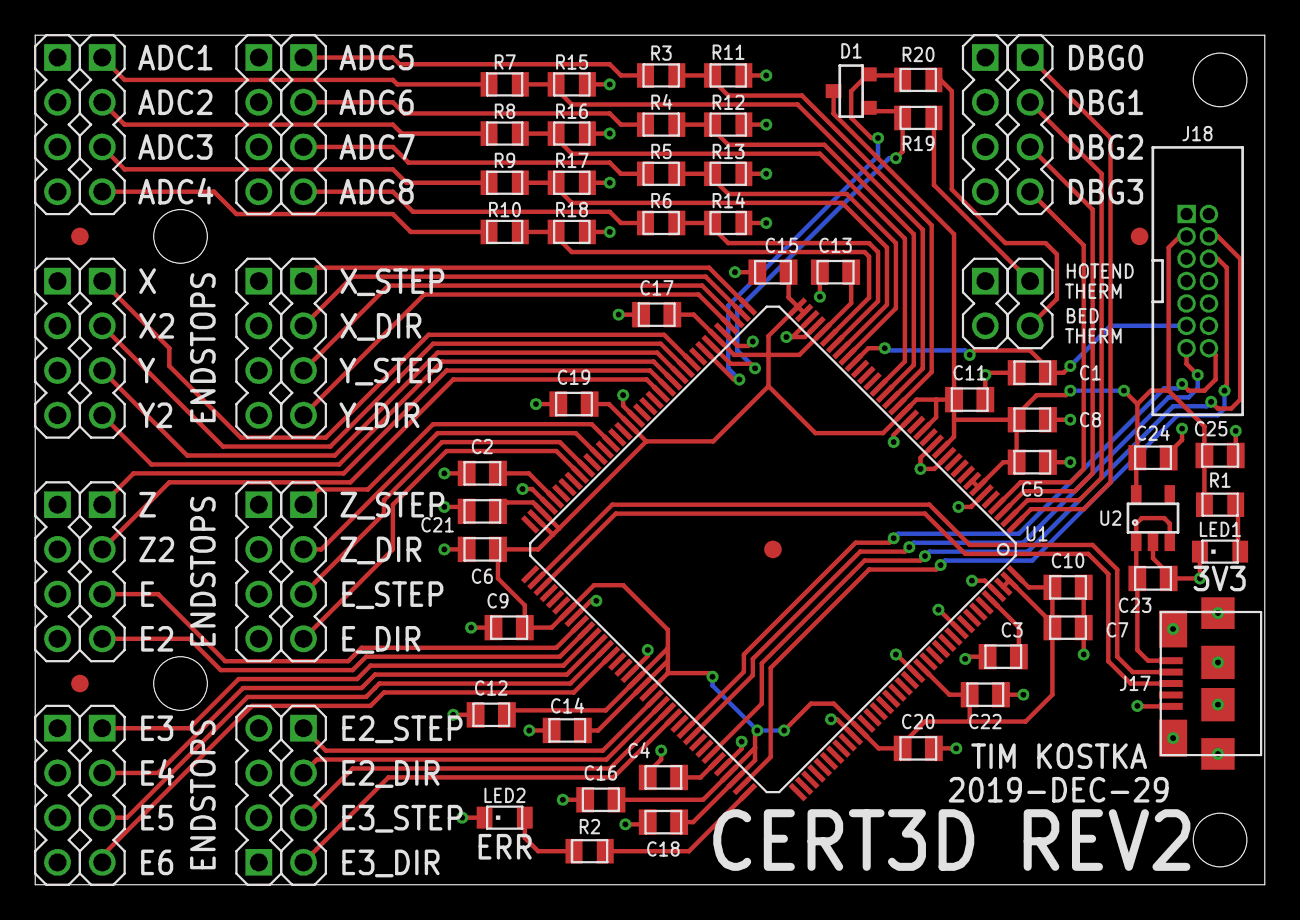
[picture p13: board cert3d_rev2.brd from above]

Board: 2 copper layers, 69.8 x 48.3 mm, 76 parts (0 on the bottom side), 64 nets.

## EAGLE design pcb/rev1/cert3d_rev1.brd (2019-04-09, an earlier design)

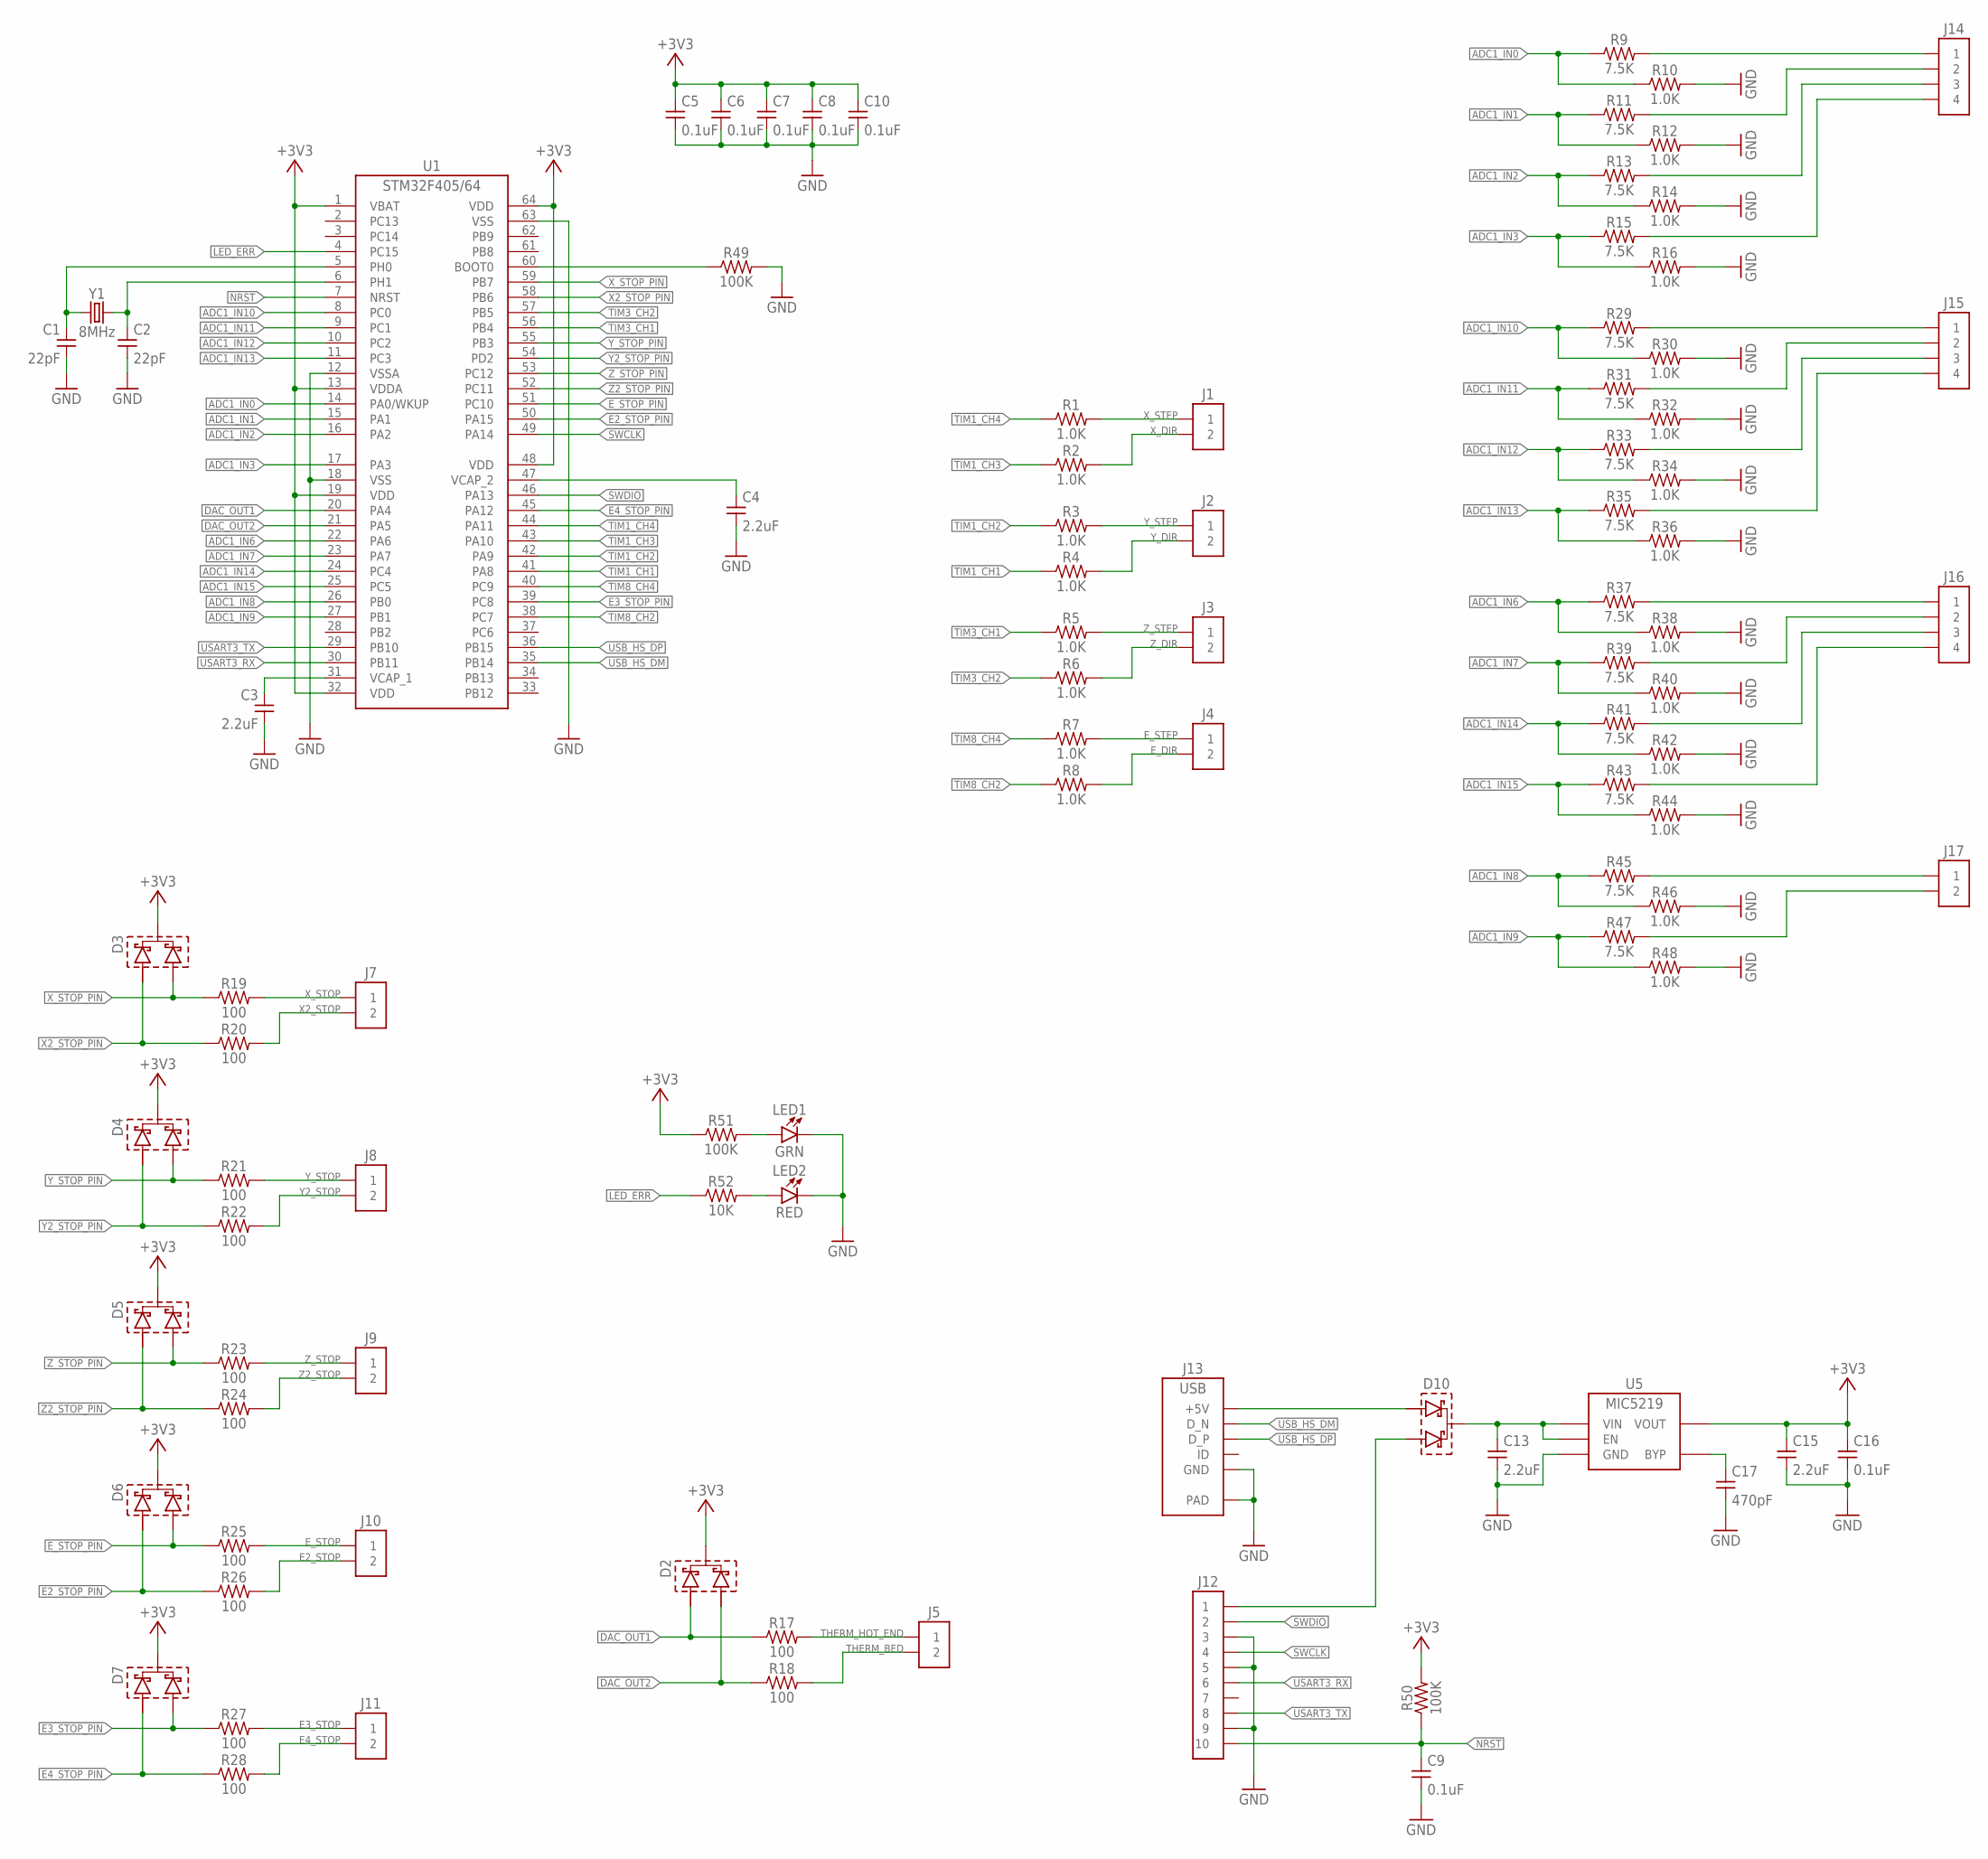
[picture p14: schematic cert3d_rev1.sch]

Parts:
C1, C2: 22pF; C0805-5MIL
C3, C4, C13, C15: 2.2uF; C0805-5MIL
C5, C6, C7, C8, C9, C10, C16: 0.1uF; C0805-5MIL
C17: 470pF; C0805-5MIL
D2, D3, D4, D5, D6, D7, D10: SCHOTTKY_DUAL_CCBAT54C; SOT23-3
J1, J2, J3, J4, J5, J7, J8, J9, J10, J11, J17: CONN2TSW-S; SAM-TSW-102-XX-X-S
J12: CONN10CNC-3220-10-0100-00; CNC-3220-10-0100-00
J13: USB-5PINTOPVIA; HIR-ZX62R-B-5P-VIAS
J14, J15, J16: CONN4TSW-S; SAM-TSW-104-XX-X-S
LED1: GRN; CHIPLED0805-SMALL
LED2: RED; CHIPLED0805-SMALL
R1, R2, R3, R4, R5, R6, R7, R8: 1.0K; RES0805R
R9, R11, R13, R15, R29, R31, R33, R35, R37, R39, R41, R43, R45, R47: 7.5K; RES0805R-5MIL
R10, R12, R14, R16, R30, R32, R34, R36, R38, R40, R42, R44, R46, R48: 1.0K; RES0805R-5MIL
R17, R18, R19, R20, R21, R22, R23, R24, R25, R26, R27, R28: 100; RES0805R-5MIL
R49, R50, R51: 100K; RES0805R-5MIL
R52: 10K; RES0805R-5MIL
U1: STM32F405/64; LQFP64-10X10MM
U5: MIC5219; SOT23-5
Y1: 8MHz; HC49US

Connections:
+3V3: C5.1, C6.1, C7.1, C8.1, C10.1, C15.1, C16.1, D2.3 (C), D3.3 (C), D4.3 (C), D5.3 (C), D6.3 (C), D7.3 (C), R50.2, R51.1, U1.1 (VBAT), U1.13 (VDDA), U1.19 (VDD), U1.32 (VDD), U1.48 (VDD), U1.64 (VDD), U5.5 (VOUT)
ADC1_IN0: R9.1, R10.1, U1.14 (PA0/WKUP)
ADC1_IN1: R11.1, R12.1, U1.15 (PA1)
ADC1_IN2: R13.1, R14.1, U1.16 (PA2)
ADC1_IN3: R15.1, R16.1, U1.17 (PA3)
ADC1_IN6: R37.1, R38.1, U1.22 (PA6)
ADC1_IN7: R39.1, R40.1, U1.23 (PA7)
ADC1_IN8: R45.1, R46.1, U1.26 (PB0)
ADC1_IN9: R47.1, R48.1, U1.27 (PB1)
ADC1_IN10: R29.1, R30.1, U1.8 (PC0)
ADC1_IN11: R31.1, R32.1, U1.9 (PC1)
ADC1_IN12: R33.1, R34.1, U1.10 (PC2)
ADC1_IN13: R35.1, R36.1, U1.11 (PC3)
ADC1_IN14: R41.1, R42.1, U1.24 (PC4)
ADC1_IN15: R43.1, R44.1, U1.25 (PC5)
DAC_OUT1: D2.1 (A1), R17.1, U1.20 (PA4)
DAC_OUT2: D2.2 (A2), R18.1, U1.21 (PA5)
E2_STOP: J10.2, R26.2
E2_STOP_PIN: D6.1 (A1), R26.1, U1.50 (PA15)
E3_STOP: J11.1, R27.2
E3_STOP_PIN: D7.2 (A2), R27.1, U1.39 (PC8)
E4_STOP: J11.2, R28.2
E4_STOP_PIN: D7.1 (A1), R28.1, U1.45 (PA12)
E_DIR: J4.2, R8.2
E_STEP: J4.1, R7.2
E_STOP: J10.1, R25.2
E_STOP_PIN: D6.2 (A2), R25.1, U1.51 (PC10)
GND: C1.2, C2.2, C3.2, C4.2, C5.2, C6.2, C7.2, C8.2, C9.2, C10.2, C13.2, C15.2, C16.2, C17.2, J12.3, J12.5, J12.9, J13.5 (GND), J13.PAD@1 (PAD), J13.PAD@2 (PAD), J13.PAD@3 (PAD), J13.PAD@4 (PAD), J13.PAD@5 (PAD), J13.PAD@6 (PAD), J13.PAD@7 (PAD), J13.PAD@8 (PAD), J13.PAD@9 (PAD), J13.PAD@10 (PAD), J13.PAD@11 (PAD), J13.PAD@12 (PAD), LED1.C, LED2.C, R10.2, R12.2, R14.2, R16.2, R30.2, R32.2, R34.2, R36.2, R38.2, R40.2, R42.2, R44.2, R46.2, R48.2, R49.2, U1.12 (VSSA), U1.18 (VSS), U1.63 (VSS), U5.2 (GND)
LED_ERR: R52.1, U1.4 (PC15)
unnamed: C2.1, U1.6 (PH1), Y1.2
unnamed: C1.1, U1.5 (PH0), Y1.1
unnamed: J14.2, R11.2
unnamed: C4.1, U1.47 (VCAP_2)
unnamed: J14.1, R9.2
unnamed: C3.1, U1.31 (VCAP_1)
unnamed: J14.3, R13.2
unnamed: J14.4, R15.2
unnamed: D10.2 (A2), J12.1
unnamed: C13.1, D10.3 (C), U5.1 (VIN), U5.3 (EN)
unnamed: J15.1, R29.2
unnamed: D10.1 (A1), J13.1 (+5V)
unnamed: J15.2, R31.2
unnamed: J15.3, R33.2
unnamed: J15.4, R35.2
unnamed: J16.1, R37.2
unnamed: J16.2, R39.2
unnamed: J16.3, R41.2
unnamed: J16.4, R43.2
unnamed: J17.1, R45.2
unnamed: J17.2, R47.2
unnamed: R49.1, U1.60 (BOOT0)
unnamed: LED2.A, R52.2
unnamed: LED1.A, R51.2
unnamed: C17.1, U5.4 (BYP)
NRST: C9.1, J12.10, R50.1, U1.7 (NRST)
SWCLK: J12.4, U1.49 (PA14)
SWDIO: J12.2, U1.46 (PA13)
THERM_BED: J5.2, R18.2
THERM_HOT_END: J5.1, R17.2
TIM1_CH1: R4.1, U1.41 (PA8)
TIM1_CH2: R3.1, U1.42 (PA9)
TIM1_CH3: R2.1, U1.43 (PA10)
TIM1_CH4: R1.1, U1.44 (PA11)
TIM3_CH1: R5.1, U1.56 (PB4)
TIM3_CH2: R6.1, U1.57 (PB5)
TIM8_CH2: R8.1, U1.38 (PC7)
TIM8_CH4: R7.1, U1.40 (PC9)
USART3_RX: J12.6, U1.30 (PB11)
USART3_TX: J12.8, U1.29 (PB10)
USB_HS_DM: J13.2 (D_N), U1.35 (PB14)
USB_HS_DP: J13.3 (D_P), U1.36 (PB15)
X2_STOP: J7.2, R20.2
X2_STOP_PIN: D3.1 (A1), R20.1, U1.58 (PB6)
X_DIR: J1.2, R2.2
X_STEP: J1.1, R1.2
X_STOP: J7.1, R19.2
X_STOP_PIN: D3.2 (A2), R19.1, U1.59 (PB7)
Y2_STOP: J8.2, R22.2
Y2_STOP_PIN: D4.1 (A1), R22.1, U1.54 (PD2)
Y_DIR: J2.2, R4.2
Y_STEP: J2.1, R3.2
Y_STOP: J8.1, R21.2
Y_STOP_PIN: D4.2 (A2), R21.1, U1.55 (PB3)
Z2_STOP: J9.2, R24.2
Z2_STOP_PIN: D5.1 (A1), R24.1, U1.52 (PC11)
Z_DIR: J3.2, R6.2
Z_STEP: J3.1, R5.2
Z_STOP: J9.1, R23.2
Z_STOP_PIN: D5.2 (A2), R23.1, U1.53 (PC12)

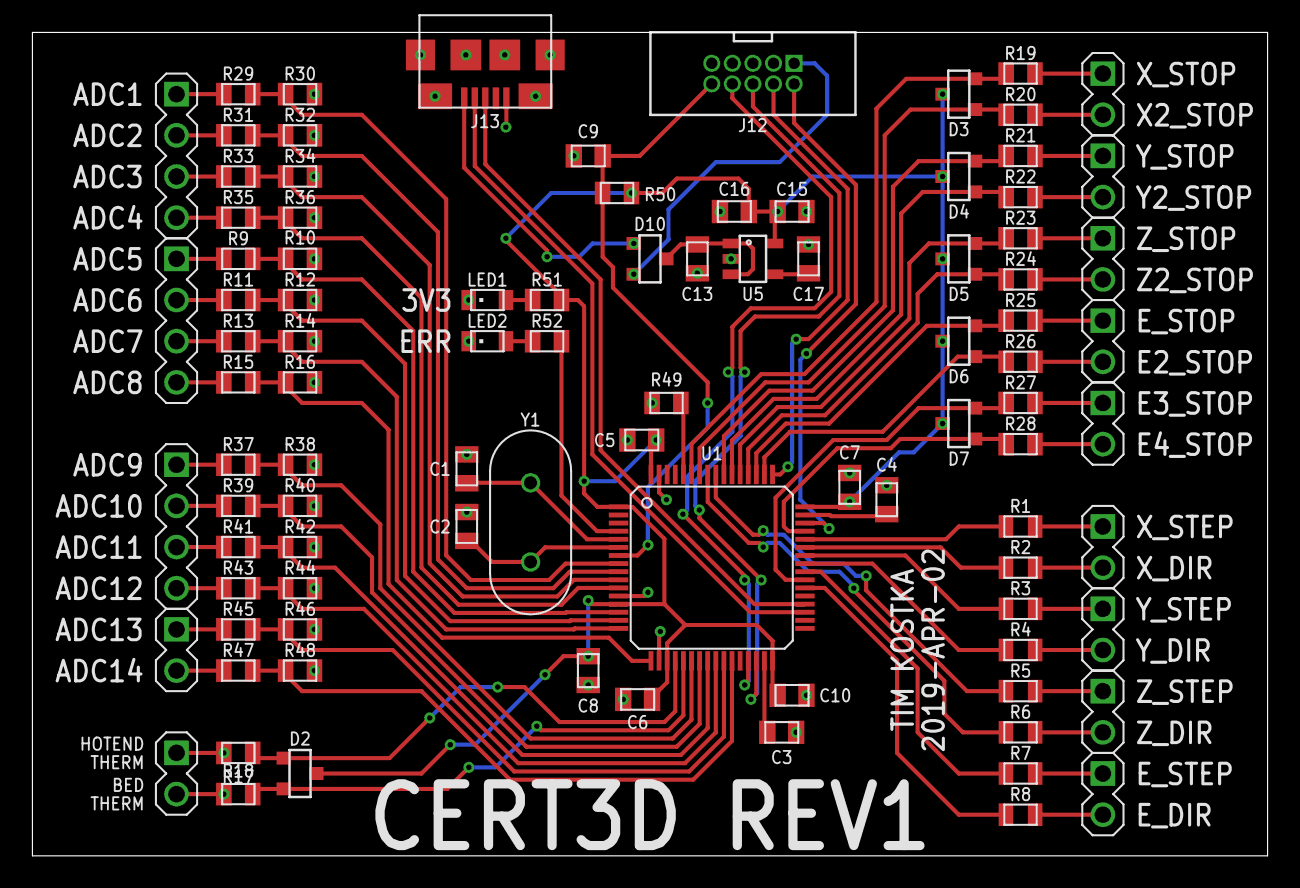
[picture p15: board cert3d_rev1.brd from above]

Board: 2 copper layers, 76.2 x 50.8 mm, 94 parts (0 on the bottom side), 89 nets.

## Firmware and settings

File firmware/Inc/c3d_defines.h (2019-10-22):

#pragma once

#include "c3d_includes.h"

// adc peripheral
ADC_TypeDef * const c3d_adc = ADC1;

// adc channels
const uint32_t c3d_adc_channel[] = {
    ADC_CHANNEL_10,
    ADC_CHANNEL_11,
    ADC_CHANNEL_12,
    ADC_CHANNEL_13,
    ADC_CHANNEL_0,
    ADC_CHANNEL_1,
    ADC_CHANNEL_2,
    ADC_CHANNEL_3,
    ADC_CHANNEL_6,
    ADC_CHANNEL_7,
    ADC_CHANNEL_14,
    ADC_CHANNEL_15,
    ADC_CHANNEL_8,
    ADC_CHANNEL_9,
};

// channel count
const uint16_t c3d_adc_channel_count =
    sizeof(c3d_adc_channel) / sizeof(*c3d_adc_channel);

// timer to use to trigger ADC readings
TIM_TypeDef * const c3d_adc_timer = TIM2;

// approximate frequency of ADC readings
const uint32_t c3d_adc_frequency = 100;

// high resistor on adc resistor divider
const float c3d_adc_high_resistor = 7500.0f;

// low resistor on adc resistor divider
const float c3d_adc_low_resistor = 1000.0f;

// ADC buffer size
const uint16_t c3d_adc_buffer_capacity = c3d_adc_channel_count * 6;

// ADC output buffer
uint16_t c3d_adc_buffer[c3d_adc_buffer_capacity];

// class for monitoring a DIR or STEP signal
struct SignalMonitorStruct {
  // name of channel
  const char * const name;
  // TIMER on this channel
  TIM_TypeDef * const TIMx;
  // timer channel
  uint32_t timer_channel;
  // DMA stream for this signal
  DMA_Stream_TypeDef * const dma_stream;
  // DMA channel
  const uint32_t dma_channel;
  // buffer
  uint16_t * buffer;
  // buffer capacity
  uint16_t const buffer_capacity;
};

// buffer for DIR signals
// must be a power of 2
const uint16_t c3d_dir_buffer_capacity = 2048;

// buffer for STEP signals
// must be a power of 2
const uint16_t c3d_step_buffer_capacity = 2048;

// channels we're monitoring
SignalMonitorStruct c3d_signal[] = {
    {"X_STEP", TIM1, TIM_CHANNEL_4, DMA2_Stream4, DMA_CHANNEL_6, nullptr, c3d_step_buffer_capacity},
    {"X_DIR", TIM1, TIM_CHANNEL_3, DMA2_Stream6, DMA_CHANNEL_6, nullptr, c3d_dir_buffer_capacity},
    {"Y_STEP", TIM1, TIM_CHANNEL_2, DMA2_Stream2, DMA_CHANNEL_6, nullptr, c3d_step_buffer_capacity},
    {"Y_DIR", TIM1, TIM_CHANNEL_1, DMA2_Stream1, DMA_CHANNEL_6, nullptr, c3d_dir_buffer_capacity},
    {"Z_STEP", TIM3, TIM_CHANNEL_1, DMA1_Stream4, DMA_CHANNEL_5, nullptr, c3d_step_buffer_capacity},
    {"Z_DIR", TIM3, TIM_CHANNEL_2, DMA1_Stream5, DMA_CHANNEL_5, nullptr, c3d_dir_buffer_capacity},
    {"E_STEP", TIM8, TIM_CHANNEL_4, DMA2_Stream7, DMA_CHANNEL_7, nullptr, c3d_step_buffer_capacity},
    {"E_DIR", TIM8, TIM_CHANNEL_2, DMA2_Stream3, DMA_CHANNEL_7, nullptr, c3d_dir_buffer_capacity},
};

// timer to trigger all other timers
TIM_TypeDef * const c3d_master_timer = TIM4;

// number of signals
const uint16_t c3d_signal_count = sizeof(c3d_signal) / sizeof(*c3d_signal);

// monitor for each signal DMA channel
C3D_SignalDmaMonitor c3d_signal_dma_monitor[c3d_signal_count];

// monitor for each signal DMA channel
//C3D_DMA_Monitor<uint16_t> c3d_signal_usb_dma_monitor[c3d_signal_count];

// step monitor for each signal channel
C3D_DMA_Monitor<uint16_t> c3d_signal_step_dma_monitor[c3d_signal_count];
//C3D_SignalDmaMonitor c3d_signal_step_dma_monitor[c3d_signal_count];

// monitor for the ADC DMA channel
C3D_DMA_Monitor<uint16_t> c3d_adc_dma_monitor;

// number of times we processed data
uint32_t c3d_process_count = 0;

// number of edges sent
uint32_t c3d_edge_count = 0xFFFFFFFF;

// averaged output bits per process
GSL_LPFVAL c3d_output_bits_per_process(10.0f);

// chunk buffer for USB data
C3D_ChunkBuffer c3d_usb_buffer;

// if true, stream data to USB
//bool c3d_output_to_usb = false;

// commands
struct CommandStruct {
  // command string
  const char * text;
  // function to call
  void (*function)(void);
};

void C3D_EnableStartStreamingFlag(void);
void C3D_EnableStopStreamingFlag(void);
void C3D_StopStreaming(void);
void C3D_SendInfoHeaderPacket(void);
void C3D_Debug(void);
void C3D_Reset(void);
void C3D_Status(void);

// commands
const CommandStruct c3d_command[] = {
    {"start", C3D_EnableStartStreamingFlag},
    {"stop", C3D_EnableStopStreamingFlag},
    {"debug", C3D_Debug},
    {"reset", C3D_Reset},
    {"status", C3D_Status},
};

// number of commands
const uint16_t c3d_command_count = sizeof(c3d_command) / sizeof(*c3d_command);

// debug flag
bool c3d_debug_flag = false;

// if True, will ignore data sent to USB
//bool c3d_ignore_usb_output = false;

// flag for enabled or disabled streaming
bool c3d_streaming_flag = false;

// target streaming flag
bool c3d_target_streaming_flag = false;

// true if first packet since streaming started
bool c3d_first_packet = false;

// number of axes
const uint16_t c3d_motor_count = c3d_signal_count / 2;
static_assert(c3d_signal_count % 2 == 0, "");

// stepper motor information
struct C3D_StepperMotorStruct {
  // steps per mm
  float steps_per_mm;
  // range in mm (or -1 if unlimited)
  float range_mm;
  // absolute position in steps
  int32_t step_position;
  // true if DIR signal is high
  bool dir_is_high;
  // true if STEP signal is high
  bool step_is_high;
  // half of the counter overflow value
  uint16_t half_counter_overflow;
  // mm range
  // steps at zero position
  int32_t zero_step_offset;
  // low endstop
  C3D_EndStopStruct low_stop;
  // high endstop
  C3D_EndStopStruct high_stop;
  // return absolute position in mm
  float GetPositionMM() const {
    return (step_position - zero_step_offset) / steps_per_mm;
  }
};

C3D_StepperMotorStruct c3d_motor[c3d_motor_count] = {
    {80.0f, 230.0f, 0, false, false, 32768, -1000, {kPinB7}, {kPinB6}},
    {80.0f, 230.0f, 0, false, false, 32768, -1000, {kPinB3}, {kPinD2}},
    {400.0f, 200.0f, 0, false, false, 32768 / 2, -1000, {kPinC12}, {kPinC11}},
    {93.0f, -1.0f, 0, false, false, 32768, -1000, {kPinC10}, {kPinA15}},
};

// printer geometry
struct C3D_PrinterGeometryStruct {
  // current absolute step position
  int32_t step_position[c3d_motor_count];
  // steps per mm
  float steps_per_mm[c3d_motor_count];
} c3d_geometry;


// debug pins
PinEnum c3d_debug_pin[4] = {kPinB6, kPinB3, kPinD2, kPinC12};

// buffer for creating packet

// if true, output ADC channels
const bool c3d_output_adc_channels = true;

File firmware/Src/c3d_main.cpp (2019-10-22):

//
// Created by tdkostk on 4/27/2019.
//

#include "c3d_includes.h"

#include "stm32f4xx_ll_adc.h"
#include "stm32f4xx_ll_tim.h"

// output timer counts
void C3D_OutputTimerCounts(void) {
  GSL_GEN_DisableInterrupts();
  uint32_t c1 = TIM1->CNT;
  uint32_t c2 = TIM2->CNT;
  uint32_t c3 = TIM3->CNT;
  uint32_t c4 = TIM4->CNT;
  uint32_t c8 = TIM8->CNT;
  GSL_GEN_EnableInterrupts();
  LOG("\nc3d=", c3d_process_count);
  LOG(", TIM1->CNT=", c1, ", TIM2->CNT=", c2, ", TIM3->CNT=", c3);
  LOG(", TIM4->CNT=", c4, ", TIM8->CNT=", c8);
}

// initialize the master timer
void C3D_InitializeMasterTimer(void) {
  auto & TIMx = c3d_master_timer;
  // enable clock
  GSL_TIM_EnableClock(TIMx);
  // disable
  CLEAR_BIT(TIMx->CR1, TIM_CR1_CEN);
  // clear interrupts
  TIMx->SR = 0;
  // set up master timer base unit
  TIMx->PSC = 0;
  ASSERT(TIMx == TIM4);
  TIMx->ARR = 0x3FFF;
  // set counter to N - 1 so it generates an update immediately
  TIMx->CNT = TIMx->ARR - 1;
  // enable TRGO on update event
  MODIFY_REG(TIMx->CR2, TIM_CR2_MMS, TIM_TRGO_UPDATE);
  // enable update interrupt
  SET_BIT(TIMx->DIER, TIM_DIER_UIE);
  // enable IRQ
  ASSERT(TIMx == TIM4);
  HAL_NVIC_SetPriority(TIM4_IRQn, 0, 0);
  HAL_NVIC_EnableIRQ(TIM4_IRQn);
}

// initialize the signal timers and related DMA streams
void C3D_InitializeSignalTimers(void) {
  // enable clocks
  for (uint16_t i = 0; i < c3d_signal_count; ++i) {
    GSL_TIM_EnableClock(c3d_signal[i].TIMx);
  }
  // clear interrupts
  for (uint16_t i = 0; i < c3d_signal_count; ++i) {
    c3d_signal[i].TIMx->SR = 0;
  }
  // disable timer
  for (uint16_t i = 0; i < c3d_signal_count; ++i) {
    CLEAR_BIT(c3d_signal[i].TIMx->CR1, TIM_CR1_CEN);
  }
  // set up timer base unit
  for (uint16_t i = 0; i < c3d_signal_count; ++i) {
    c3d_signal[i].TIMx->PSC = 0;
    if (c3d_signal[i].TIMx == TIM1 || c3d_signal[i].TIMx == TIM8) {
      c3d_signal[i].TIMx->ARR = 0xFFFF;
    } else {
      ASSERT(c3d_signal[i].TIMx == TIM3);
      c3d_signal[i].TIMx->ARR = 0x7FFF;
    }
    c3d_signal[i].TIMx->CNT = 0;
  }
  // set up timer IC channels
  for (uint16_t i = 0; i < c3d_signal_count; ++i) {
    auto & signal = c3d_signal[i];
    auto & TIMx = c3d_signal[i].TIMx;
    // set filter of 2 samples and set mode to 01
    {
      auto reg = &TIMx->CCMR1;
      reg += (signal.timer_channel / 4) / 2;
      uint32_t mask = 0xFF;
      uint32_t config = 0b00010001;
      *reg &= ~mask << (((signal.timer_channel / 4) % 2) * 8);
      *reg |= config << (((signal.timer_channel / 4) % 2) * 8);
    }
    // set CCxE = 1 to enable capture
    // set CCxNP/CCxP to 11 to enable capture on both rising and falling edges
    {
      auto & reg = TIMx->CCER;
      uint32_t mask = 0b1111;
      uint32_t config = TIM_CCER_CC1E | TIM_CCER_CC1P | TIM_CCER_CC1NP;
      reg &= ~(mask << ((signal.timer_channel / 4) * 4));
      reg |= config << ((signal.timer_channel / 4) * 4);
    }
  }
  // set to enable when master timer triggers
  for (uint16_t i = 0; i < c3d_signal_count; ++i) {
    auto & TIMx = c3d_signal[i].TIMx;
    uint32_t source = GSL_TIM_GetInternalTrigger(TIMx, c3d_master_timer);
    MODIFY_REG(TIMx->SMCR, TIM_SMCR_TS, source);
    MODIFY_REG(TIMx->SMCR, TIM_SMCR_SMS, TIM_SLAVEMODE_TRIGGER);
  }
  // enable DIER_CCxDE bits to enable DMA request on CC event
  for (uint16_t i = 0; i < c3d_signal_count; ++i) {
    auto & signal = c3d_signal[i];
    SET_BIT(signal.TIMx->DIER, TIM_DIER_CC1DE << (signal.timer_channel / 4));
  }
  // set up DMA signal channels
  for (uint16_t i = 0; i < c3d_signal_count; ++i) {
    auto & signal = c3d_signal[i];
    auto & TIMx = signal.TIMx;
    auto & stream = signal.dma_stream;
    // enable clock
    GSL_DMA_EnableClock(GSL_DMA_GetBase(stream));
    // disable
    CLEAR_BIT(stream->CR, DMA_SxCR_EN);
    // clear register
    stream->CR = 0;
    // set channel selection
    MODIFY_REG(stream->CR, DMA_SxCR_CHSEL, signal.dma_channel);
    // set memory size
    MODIFY_REG(stream->CR, DMA_SxCR_MSIZE, DMA_MDATAALIGN_HALFWORD);
    // set peripheral size
    MODIFY_REG(stream->CR, DMA_SxCR_PSIZE, DMA_PDATAALIGN_HALFWORD);
    // set memory increment
    MODIFY_REG(stream->CR, DMA_SxCR_MINC, DMA_MINC_ENABLE);
    // set circular mode
    MODIFY_REG(stream->CR, DMA_SxCR_CIRC, DMA_CIRCULAR);
    // set highest priority
    MODIFY_REG(stream->CR, DMA_SxCR_PL, DMA_PRIORITY_VERY_HIGH);
    // set direction
    MODIFY_REG(stream->CR, DMA_SxCR_DIR, DMA_PERIPH_TO_MEMORY);
    // set number of transfers to do
    stream->NDTR = signal.buffer_capacity;
    // set peripheral address
    stream->PAR = (uint32_t) &(
        (signal.timer_channel == TIM_CHANNEL_1) ? TIMx->CCR1 :
        (signal.timer_channel == TIM_CHANNEL_2) ? TIMx->CCR2 :
        (signal.timer_channel == TIM_CHANNEL_3) ? TIMx->CCR3 : TIMx->CCR4);
    // set memory address
    stream->M0AR = (uint32_t) signal.buffer;
    // enable DMA stream
    SET_BIT(stream->CR, DMA_SxCR_EN);
  }
}

// initialize the ADC timer and related DMA stream
void C3D_InitializeADC(void) {
  auto & ADCx = c3d_adc;
  auto & TIMx = c3d_adc_timer;
  // set up the ADC itself
  {
    GSL_ADC_EnableClock(ADCx);
    // set values to default
    ADCx->CR1 = 0;
    ADCx->CR2 = 0;
    // disable the ADC
    CLEAR_BIT(ADCx->CR2, ADC_CR2_ADON);
    // enable scan mode (convert all channels on trigger)
    SET_BIT(ADCx->CR1, ADC_CR1_SCAN);
    // trigger on TRGO rising edge
    MODIFY_REG(ADCx->CR2, ADC_CR2_EXTEN, ADC_EXTERNALTRIGCONVEDGE_RISING);
    // trigger off of TIM_TRGO signal
    MODIFY_REG(ADCx->CR2, ADC_CR2_EXTSEL, ADC_EXTERNALTRIGCONV_T2_TRGO);
    // enable DMA
    SET_BIT(ADCx->CR2, ADC_CR2_DDS);
    SET_BIT(ADCx->CR2, ADC_CR2_DMA);
    // set number of channels to convert
    {
      uint32_t mask = 0b1111;
      uint32_t value = c3d_adc_channel_count - 1;
      mask <<= ADC_SQR1_L_Pos;
      value <<= ADC_SQR1_L_Pos;
      ADCx->SQR1 &= ~mask;
      ADCx->SQR1 |= value;
    }
    // configure channels
    for (uint16_t i = 0; i < c3d_adc_channel_count; ++i) {
      // set sampling time
      {
        __IO uint32_t * reg = &c3d_adc->SMPR2;
        reg -= (i / 10);
        uint32_t mask = 0b111;
        uint32_t value = ADC_SAMPLETIME_480CYCLES;
        *reg &= ~(mask << ((i % 10) * 3));
        *reg |= value << ((i % 10) * 3);
      }
      // set this rank to convert this channel
      {
        __IO uint32_t * reg = &c3d_adc->SQR3;
        reg -= (i / 6);
        uint32_t mask = 0b11111;
        uint32_t value = c3d_adc_channel[i];
        *reg &= ~(mask << ((i % 6) * 5));
        *reg |= value << ((i % 6) * 5);
      }
    }
    // turn on the ADC
    SET_BIT(ADCx->CR2, ADC_CR2_ADON);
  }
  // set up ADC timer
  {
    // enable the clock
    GSL_TIM_EnableClock(TIMx);
    // clear interrupts
    TIMx->SR = 0;
    CLEAR_BIT(TIMx->CR1, TIM_CR1_CEN);
    // ensure frequency is an integer number of ticks
    uint32_t timer_frequency = HAL_RCC_GetHCLKFreq() / 2;
    ASSERT_EQ(timer_frequency % c3d_adc_frequency, 0);
    //
    uint32_t timer_ticks_per_sample = timer_frequency / c3d_adc_frequency;
    ASSERT_GT(timer_ticks_per_sample, 0);
    uint32_t prescaler = 1;
    uint32_t reload = timer_ticks_per_sample;
    while (reload > 65536) {
      uint32_t factor = 2;
      while (reload % factor != 0) {
        ++factor;
      }
      ASSERT_EQ(reload % factor, 0);
      reload /= factor;
      prescaler *= factor;
      ASSERT_LE(prescaler, 65536);
    }
    ASSERT_GT(reload, 1);
    // set up timer base unit
    TIMx->PSC = prescaler - 1;
    TIMx->ARR = reload - 1;
    TIMx->CNT = 0;
    // set update event as TRGO output
    MODIFY_REG(TIMx->CR2, TIM_CR2_MMS, LL_TIM_TRGO_UPDATE);
    // set to enable when master timer triggers
    uint32_t source = GSL_TIM_GetInternalTrigger(TIMx, c3d_master_timer);
    MODIFY_REG(TIMx->SMCR, TIM_SMCR_TS, source);
    MODIFY_REG(TIMx->SMCR, TIM_SMCR_SMS, TIM_SLAVEMODE_TRIGGER);
  }
  // set up ADC DMA stream
  {
    auto & stream = c3d_adc_dma_monitor.dma_stream;
    // enable clock
    GSL_DMA_EnableClock(GSL_DMA_GetBase(stream));
    // disable
    CLEAR_BIT(stream->CR, DMA_SxCR_EN);
    // clear register
    stream->CR = 0;
    // set channel selection
    {
      ASSERT(c3d_adc == ADC1 || c3d_adc == ADC2 || c3d_adc == ADC3);
      uint32_t chsel =
          (c3d_adc == ADC1) ? DMA_CHANNEL_0 :
          (c3d_adc == ADC2) ? DMA_CHANNEL_1 :
          (c3d_adc == ADC3) ? DMA_CHANNEL_2 : 0;
      MODIFY_REG(stream->CR, DMA_SxCR_CHSEL, chsel);
    }
    // set memory size
    MODIFY_REG(stream->CR, DMA_SxCR_MSIZE, DMA_MDATAALIGN_HALFWORD);
    // set peripheral size
    MODIFY_REG(stream->CR, DMA_SxCR_PSIZE, DMA_PDATAALIGN_HALFWORD);
    // set memory increment
    MODIFY_REG(stream->CR, DMA_SxCR_MINC, DMA_MINC_ENABLE);
    // set circular mode
    MODIFY_REG(stream->CR, DMA_SxCR_CIRC, DMA_CIRCULAR);
    // set high priority (below signal channels)
    MODIFY_REG(stream->CR, DMA_SxCR_PL, DMA_PRIORITY_HIGH);
    // set direction
    MODIFY_REG(stream->CR, DMA_SxCR_DIR, DMA_PERIPH_TO_MEMORY);
    // set number of transfers to do
    stream->NDTR = c3d_adc_buffer_capacity;
    // set peripheral address
    stream->PAR = (uint32_t) &(c3d_adc->DR);
    // set memory address
    stream->M0AR = (uint32_t) c3d_adc_buffer;
    // enable DMA stream
    SET_BIT(stream->CR, DMA_SxCR_EN);
  }
}

// initialize signal timers and DMA stuff
/*void C3D_InitTimers(void) {
  // initialize the master clock
  {}
  // enable clocks
  __HAL_RCC_TIM1_CLK_ENABLE();
  __HAL_RCC_TIM3_CLK_ENABLE();
  __HAL_RCC_TIM4_CLK_ENABLE();
  __HAL_RCC_TIM8_CLK_ENABLE();
  // disable timer and
  // disable timers
  TIM1->CR1 &= ~TIM_CR1_CEN;
  TIM3->CR1 &= ~TIM_CR1_CEN;
  TIM4->CR1 &= ~TIM_CR1_CEN;
  TIM8->CR1 &= ~TIM_CR1_CEN;
  // zero out count
  TIM1->CNT = 0;
  TIM3->CNT = 0;
  TIM4->CNT = 0;
  TIM8->CNT = 0;
  // set prescalers
  TIM1->PSC = 0;
  TIM3->PSC = 0;
  TIM4->PSC = 0;
  TIM8->PSC = 0;
  // set ARR
  TIM1->ARR = 0xFFFF;
  TIM3->ARR = 0x7FFF;
  TIM4->ARR = 0x3FFF;
  TIM8->ARR = 0xFFFF;

  // set up IC channels
  TIM_TypeDef * TIMx = nullptr;
  // TIM1->CH4
  TIMx = TIM1;
  GSL_PIN_InitializeAF(kPinA11, GPIO_MODE_AF_PP, GPIO_NOPULL, GPIO_AF1_TIM1);
  CLEAR_BIT(TIMx->CCMR2, TIM_CCMR2_OC4CE);
  MODIFY_REG(TIMx->CCMR2, TIM_CCMR2_OC4M, TIM_OCMODE_PWM1 << 8);
  SET_BIT(TIMx->CCMR2, TIM_CCMR2_OC4PE);
  TIMx->CCR4 = 0x8000;
  SET_BIT(TIMx->BDTR, TIM_BDTR_MOE);
  SET_BIT(TIMx->CCER, TIM_CCER_CC4E);
  // set to trigger when TIM4 enables
  MODIFY_REG(TIMx->SMCR, TIM_SMCR_TS, TIM_CLOCKSOURCE_ITR3);
  MODIFY_REG(TIMx->SMCR, TIM_SMCR_SMS, TIM_SLAVEMODE_TRIGGER);

  // TIM3->CH1
  TIMx = TIM3;
  GSL_PIN_InitializeAF(kPinB4, GPIO_MODE_AF_PP, GPIO_NOPULL, GPIO_AF2_TIM3);
  CLEAR_BIT(TIMx->CCMR1, TIM_CCMR1_OC1CE);
  MODIFY_REG(TIMx->CCMR1, TIM_CCMR1_OC1M, TIM_OCMODE_PWM1);
  SET_BIT(TIMx->CCMR1, TIM_CCMR1_OC1PE);
  TIMx->CCR1 = 0x4000;
  SET_BIT(TIMx->CCER, TIM_CCER_CC1E);
  // set to trigger when TIM4 enables
  MODIFY_REG(TIMx->SMCR, TIM_SMCR_TS, TIM_CLOCKSOURCE_ITR3);
  MODIFY_REG(TIMx->SMCR, TIM_SMCR_SMS, TIM_SLAVEMODE_TRIGGER);

  // TIM8->CH4
  TIMx = TIM8;
  GSL_PIN_InitializeAF(kPinC9, GPIO_MODE_AF_PP, GPIO_NOPULL, GPIO_AF3_TIM8);
  CLEAR_BIT(TIMx->CCMR2, TIM_CCMR2_OC4CE);
  MODIFY_REG(TIMx->CCMR2, TIM_CCMR2_OC4M, TIM_OCMODE_PWM1 << 8);
  SET_BIT(TIMx->CCMR2, TIM_CCMR2_OC4PE);
  TIMx->CCR4 = 0x8000;
  SET_BIT(TIMx->BDTR, TIM_BDTR_MOE);
  SET_BIT(TIMx->CCER, TIM_CCER_CC4E);
  // set to trigger when TIM4 enables
  MODIFY_REG(TIMx->SMCR, TIM_SMCR_TS, TIM_CLOCKSOURCE_ITR2);
  MODIFY_REG(TIMx->SMCR, TIM_SMCR_SMS, TIM_SLAVEMODE_TRIGGER);

  TIM1->CNT = 1;
  TIM3->CNT = 2;
  TIM8->CNT = 1;

  // enable master timer
  TIMx = TIM4;
  MODIFY_REG(TIMx->CR2, TIM_CR2_MMS, TIM_TRGO_UPDATE);

  // enable master timer
  SET_BIT(TIM4->CR1, TIM_CR1_CEN);
  //TIM4->EGR = TIM_EGR_UG;
  //SET_BIT(TIM4->DIER, TIM_DIER_UIE);

  GSL_DEL_MS(1);
  LOG("\nTIM4->CNT=", TIM4->CNT);
  GSL_DEL_MS(1);
  LOG("\nTIM4->CNT=", TIM4->CNT);
  GSL_DEL_MS(1);
  LOG("\nTIM4->CNT=", TIM4->CNT);
  GSL_DEL_MS(1);
  LOG("\nTIM4->CNT=", TIM4->CNT);

  //GSL_TIM_LogDetailedInformation();

  // wait for timer to roll over
  for (uint16_t i = 0; i < 10; ++i) {
    uint32_t count = TIM4->CNT;
    uint32_t next = TIM4->CNT;
    while (count < next) {
      count = next;
      next = TIM4->CNT;
    }
    C3D_OutputTimerCounts();
  }

  while (1) {
    LIMITED_LOG(5, "\nTIM1->CNT=", TIM1->CNT);
    GSL_PIN_Toggle(c3d_debug_pin[0]);
  }

}*/

// create and send a new data packet
void C3D_CreatePacket(void) {

  // quickly, store the head index for each channel
  for (uint16_t s = 0; s < c3d_signal_count; ++s) {
    auto & monitor = c3d_signal_dma_monitor[s];
    monitor.head_index = monitor.GetHeadIndex();
  }
  // if first packet, skip all edges
  if (c3d_first_packet) {
    c3d_first_packet = false;
    for (uint16_t s = 0; s < c3d_signal_count; ++s) {
      auto & monitor = c3d_signal_dma_monitor[s];
      monitor.tail_index = monitor.head_index;
      monitor.middle_index = monitor.head_index;
    }
  }

  // number of bytes added by this packet
  uint16_t byte_count = 0;

  // for each signal, increment middle_index to end of edges to send
  for (uint16_t s = 0; s < c3d_signal_count; ++s) {
    // alias DMA buffer monitor for this channel
    auto & monitor = c3d_signal_dma_monitor[s];
    const auto & capacity = monitor.capacity;
    const auto & middle_index = monitor.middle_index;
    // move middle edge to end of edges to send
    uint32_t head_index = monitor.head_index;
    while (head_index != middle_index &&
        monitor.buffer[(head_index + capacity - 1) % capacity] <
            monitor.middle_count) {
      head_index = (head_index + capacity - 1) % capacity;
    }
    monitor.middle_index = head_index;
  }

  // output packet number
  c3d_usb_buffer.StageVariable((uint8_t) (c3d_process_count / 2));
  ++byte_count;

  // create channel mask
  uint8_t channel_mask = 0;
  for (uint16_t s = 0; s < c3d_signal_count; ++s) {
    auto & monitor = c3d_signal_dma_monitor[s];
    if (monitor.middle_index != monitor.tail_index) {
      channel_mask |= 1 << s;
    }
  }

  // add channel mask
  c3d_usb_buffer.StageVariable(channel_mask);
  ++byte_count;

  // add edges for each signal
  for (uint16_t s = 0; s < c3d_signal_count; ++s) {
    // skip channel if it has no edges
    if ((channel_mask & (1 << s)) == 0) {
      continue;
    }
    // alias DMA buffer monitor for this channel
    auto & monitor = c3d_signal_dma_monitor[s];
    // count edges
    uint16_t count =
        (monitor.middle_index + monitor.capacity - monitor.tail_index) %
        monitor.capacity;
    // ensure count is as expected
    if (count >= 256) {
      LIMITED_RUN(10) {
        LOG("\nc3d = ", c3d_process_count);
        LOG(", tail_index = ", monitor.tail_index);
        LOG(", middle_index = ", monitor.middle_index);
        LOG(", count = ", count);
        LOG(", capacity = ", monitor.capacity);
      }
      count = 255;
    }
    //ASSERT_GT(count, 0);
    //ASSERT_LT(count, 256);
    // add number of edges for this signal packet
    c3d_usb_buffer.StageVariable((uint8_t) count);
    ++byte_count;
    // add edge counts
    while (count--) {
      // store this edge
      c3d_usb_buffer.StageVariable(monitor.buffer[monitor.tail_index]);
      // increment index
      monitor.tail_index = (monitor.tail_index + 1) % monitor.capacity;
      byte_count += 2;
    }
    monitor.tail_index = monitor.middle_index;
  }

  // output ADC info
  if (c3d_output_adc_channels) {
    // add ADC signals
    uint8_t sample_count =
        c3d_adc_dma_monitor.GetAvailable() / c3d_adc_channel_count;
    c3d_usb_buffer.StageVariable(sample_count);
    ++byte_count;
    for (uint16_t i = 0; i < sample_count; ++i) {
      for (uint16_t s = 0; s < c3d_adc_channel_count; ++s) {
        uint16_t value = c3d_adc_dma_monitor.Pop();
        c3d_usb_buffer.StageVariable(value);
      }
    }
    byte_count += sample_count * c3d_adc_channel_count * sizeof(uint16_t);
  } else {
    c3d_usb_buffer.StageVariable((uint8_t) 0);
    ++byte_count;
  }

  // update bits per packet
  c3d_output_bits_per_process.Update(byte_count * 8);

}


// callback timer

extern "C" {

void TIM4_IRQHandler(void) {
  GSL_PIN_SetHigh(c3d_debug_pin[0]);
  // clear update bit
  TIM4->SR = ~TIM_SR_UIF;
  // if not outputting, just return
  if (!c3d_streaming_flag) {
    GSL_PIN_SetLow(c3d_debug_pin[0]);
    return;
  }
  // increment process count
  ++c3d_process_count;
  // on odd counters, update middle index
  if (c3d_process_count % 2) {
    for (uint16_t s = 0; s < c3d_signal_count; ++s) {
      // alias DMA buffer monitor for this channel
      auto & monitor = c3d_signal_dma_monitor[s];
      monitor.middle_index = monitor.GetHeadIndex();
    }
  } else {
    C3D_CreatePacket();
  }
  // update
  GSL_PIN_SetLow(c3d_debug_pin[0]);
}

}

// stop streaming data
void C3D_StopStreaming(void) {
  LOG("\nStopping stream");
  // stop timers, disable DMA requests, clear flags
  __disable_irq();
  CLEAR_BIT(c3d_master_timer->CR1, TIM_CR1_CEN);
  CLEAR_BIT(c3d_adc_timer->CR1, TIM_CR1_CEN);
  for (uint16_t i = 0; i < c3d_signal_count; ++i) {
    auto & TIMx = c3d_signal[i].TIMx;
    CLEAR_BIT(TIMx->CR1, TIM_CR1_CEN);
    TIMx->DIER = 0;
    TIMx->SR = 0;
  }
  // disable DMA
  for (uint16_t i = 0; i < c3d_signal_count; ++i) {
    auto & TIMx = c3d_signal[i].TIMx;
    auto & stream = c3d_signal[i].dma_stream;
    CLEAR_BIT(stream->CR, DMA_SxCR_EN);
    while (READ_BIT(stream->CR, DMA_SxCR_EN)) {
    }
    stream->NDTR = 0;
  }
  // advance chunk so everything gets sent out
  c3d_usb_buffer.AdvanceChunk();
  __enable_irq();
}

// set the start streaming flag
void C3D_EnableStartStreamingFlag(void) {
  c3d_target_streaming_flag = true;
}

// set the start streaming flag
void C3D_EnableStopStreamingFlag(void) {
  c3d_target_streaming_flag = false;
}

// start streaming data
void C3D_StartStreaming(void) {
  LOG("\nStarting data stream.");
  // ensure we're not in an interrupt
  ASSERT(!GSL_GEN_InInterrupt());
  // initialize master timer (but don't start it)
  C3D_InitializeMasterTimer();
  // initialize signal timers
  C3D_InitializeSignalTimers();
  // initialize adc timer
  C3D_InitializeADC();
  // set first packet flag
  c3d_first_packet = true;
  // ensure all timers are disabled
  ASSERT(READ_BIT(c3d_master_timer->CR1, TIM_CR1_CEN) == 0);
  ASSERT(READ_BIT(c3d_adc_timer->CR1, TIM_CR1_CEN) == 0);
  for (uint16_t i = 0; i < c3d_signal_count; ++i) {
    ASSERT(READ_BIT(c3d_signal[i].TIMx->CR1, TIM_CR1_CEN) == 0);
  }
  // ensure counters are at 0
  ASSERT(c3d_adc_timer->CNT == 0);
  for (uint16_t i = 0; i < c3d_signal_count; ++i) {
    ASSERT(c3d_signal[i].TIMx->CNT == 0);
  }
  // read all data from DMA monitors
  {
    auto & monitor = c3d_adc_dma_monitor;
    monitor.buffer_capacity = c3d_adc_buffer_capacity;
    monitor.Clear();
  }
  for (uint16_t i = 0; i < c3d_signal_count; ++i) {
    auto & monitor = c3d_signal_dma_monitor[i];
    monitor.tail_index = monitor.GetHeadIndex();
    monitor.middle_index = monitor.GetHeadIndex();
    c3d_signal_step_dma_monitor[i].buffer_capacity = monitor.capacity;
    c3d_signal_step_dma_monitor[i].Clear();
  }
  // look at signals and if they are high, trigger the IC DMA request flag
  // (this is so signals have the correct polarity)
  for (uint16_t i = 0; i < c3d_signal_count; ++i) {
    auto & signal = c3d_signal[i];
    auto pin = GSL_TIM_GetChannelPin(signal.TIMx, signal.timer_channel);
    if (GSL_PIN_GetValue(pin)) {
      LOG("\nChannel ", i, " pin is high!");
      if (c3d_signal[i].timer_channel == TIM_CHANNEL_1) {
        SET_BIT(c3d_signal[i].TIMx->EGR, TIM_EGR_CC1G);
      } else if (c3d_signal[i].timer_channel == TIM_CHANNEL_2) {
        SET_BIT(c3d_signal[i].TIMx->EGR, TIM_EGR_CC2G);
      } else if (c3d_signal[i].timer_channel == TIM_CHANNEL_3) {
        SET_BIT(c3d_signal[i].TIMx->EGR, TIM_EGR_CC3G);
      } else if (c3d_signal[i].timer_channel == TIM_CHANNEL_4) {
        SET_BIT(c3d_signal[i].TIMx->EGR, TIM_EGR_CC4G);
      } else {
        HALT("Unexpected value");
      }
    }
  }
  // reset process counter
  c3d_process_count = 0xFFFFFFFF;
  if (false) {
    LIMITED_RUN(1) {
      GSL_TIM_LogDetailedInformation();
      GSL_DMA_LogDetailedInformation(DMA1);
      GSL_DMA_LogDetailedInformation(DMA2);
      for (uint16_t i = 0; i < c3d_signal_count; ++i) {
        GSL_DMA_LogDetailedStreamInformation(c3d_signal[i].dma_stream);
      }
      GSL_DMA_LogDetailedStreamInformation(c3d_adc_dma_monitor.dma_stream);
      GSL_ADC_LogDetailedInformation(c3d_adc);
    }
  }
  // send info header packet
  C3D_SendInfoHeaderPacket();
  // enable the master timer
  SET_BIT(c3d_master_timer->CR1, TIM_CR1_CEN);
  // enable DIER_CCxDE bits to enable DMA requests on CC event
  for (uint16_t i = 0; i < c3d_signal_count; ++i) {
    auto & signal = c3d_signal[i];
    SET_BIT(signal.TIMx->DIER, TIM_DIER_CC1DE << (signal.timer_channel / 4));
  }
  // verify all timers have started
  if (true) {
    GSL_DEL_MS(1);
    // ensure all timers are enabled
    ASSERT(READ_BIT(c3d_master_timer->CR1, TIM_CR1_CEN));
    ASSERT(READ_BIT(c3d_adc_timer->CR1, TIM_CR1_CEN));
    for (uint16_t i = 0; i < c3d_signal_count; ++i) {
      ASSERT(READ_BIT(c3d_signal[i].TIMx->CR1, TIM_CR1_CEN));
    }
  }

}

// send info packet
void C3D_Debug(void) {
  c3d_debug_flag = true;
}

// reset the board
void C3D_Reset(void) {
  GSL_DEL_MS(100);
  GSL_GEN_DisableInterrupts();
  NVIC_SystemReset();
}
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

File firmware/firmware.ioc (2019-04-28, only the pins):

Mcu.UserName=STM32F405RGTx
PA0-WKUP.Signal=ADCx_IN0
PA1.Signal=ADCx_IN1
PA10.Signal=S_TIM1_CH3
PA11.Signal=S_TIM1_CH4
PA12.GPIO_Label=E4_STOP
PA12.Signal=GPIO_Output
PA13.Signal=SYS_JTMS-SWDIO
PA14.Signal=SYS_JTCK-SWCLK
PA15.GPIO_Label=E2_STOP
PA15.Signal=GPIO_Output
PA2.Signal=ADCx_IN2
PA3.Signal=ADCx_IN3
PA4.Signal=COMP_DAC1_group
PA5.Signal=COMP_DAC2_group
PA6.Signal=ADCx_IN6
PA7.Signal=ADCx_IN7
PA8.Signal=S_TIM1_CH1
PA9.Signal=S_TIM1_CH2
PB0.Signal=ADCx_IN8
PB1.Signal=ADCx_IN9
PB10.Signal=USART3_TX
PB11.Signal=USART3_RX
PB14.Signal=USB_OTG_HS_DM
PB15.Signal=USB_OTG_HS_DP
PB3.GPIO_Label=Y_STOP
PB3.Signal=GPIO_Output
PB4.Signal=S_TIM3_CH1
PB5.Signal=S_TIM3_CH2
PB6.GPIO_Label=X2_STOP
PB6.Signal=GPIO_Output
PB7.GPIO_Label=X_STOP
PB7.Signal=GPIO_Output
PC0.Signal=ADCx_IN10
PC1.Signal=ADCx_IN11
PC10.GPIO_Label=E_STOP
PC10.Signal=GPIO_Output
PC11.GPIO_Label=Z2_STOP
PC11.Signal=GPIO_Output
PC12.GPIO_Label=Z_STOP
PC12.Signal=GPIO_Output
PC15-OSC32_OUT.GPIO_Label=LED_ERR
PC15-OSC32_OUT.Signal=GPIO_Output
PC2.Signal=ADCx_IN12
PC3.Signal=ADCx_IN13
PC4.Signal=ADCx_IN14
PC5.Signal=ADCx_IN15
PC7.Signal=S_TIM8_CH2
PC8.GPIO_Label=E3_STOP
PC8.Signal=GPIO_Output
PC9.Signal=S_TIM8_CH4
PD2.GPIO_Label=Y2_STOP
PD2.Signal=GPIO_Output
PH0-OSC_IN.Signal=RCC_OSC_IN
PH1-OSC_OUT.Signal=RCC_OSC_OUT

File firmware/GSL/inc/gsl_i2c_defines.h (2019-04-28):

#pragma once

// This provides a interface to configure and use the I2C peripherals.

#include "gsl_includes.h"

// I2C pins
struct GSL_I2C_PinsStruct {
  PinEnum scl;
  PinEnum sda;
};

// max timeout in milliseconds used within the HAL I2C functions
#ifndef GSL_I2C_TIMEOUT
#define GSL_I2C_TIMEOUT 100
#endif

// defaults

// default clock speed
#ifndef GSL_I2C_CLOCKSPEED_DEFAULT
#define GSL_I2C_CLOCKSPEED_DEFAULT 400000
#endif

// default slave address
#ifndef GSL_I2C_SLAVEADDRESS_DEFAULT
#define GSL_I2C_SLAVEADDRESS_DEFAULT 0x00
#endif

// ************
// *** I2C1 ***
// ************

// initialize I2C1 settings
#ifdef I2C1

// clock speed
#ifndef GSL_I2C1_CLOCKSPEED
#define GSL_I2C1_CLOCKSPEED GSL_I2C_CLOCKSPEED_DEFAULT
#endif

// slave address
#ifndef GSL_I2C1_SLAVEADDRESS
#define GSL_I2C1_SLAVEADDRESS GSL_I2C_SLAVEADDRESS_DEFAULT
#endif

// scl pin
// I2C1 SCL can be PB6, PB8
#ifndef GSL_I2C1_PIN_SCL
#define GSL_I2C1_PIN_SCL kPinB6
#endif

// sda pin
// I2C1 SDA can be PB7, PB9
#ifndef GSL_I2C1_PIN_SDA
#define GSL_I2C1_PIN_SDA kPinB7
#endif

// initialization routine
I2C_HandleTypeDef gsl_i2c1_hi2c = {
    I2C1,
    {
        GSL_I2C1_CLOCKSPEED,
        I2C_DUTYCYCLE_2,
        GSL_I2C1_SLAVEADDRESS,
        I2C_ADDRESSINGMODE_7BIT,
        I2C_DUALADDRESS_DISABLE,
        0,
        I2C_GENERALCALL_DISABLE,
        I2C_NOSTRETCH_DISABLE},
    nullptr,
    0,
    0,
    0,
    0,
    nullptr,
    nullptr,
    HAL_UNLOCKED,
    HAL_I2C_STATE_RESET,
    HAL_I2C_MODE_NONE,
    HAL_I2C_ERROR_NONE,
    0,
    0,
    0,
    0};

// pins
GSL_I2C_PinsStruct gsl_i2c1_pins = {
    GSL_I2C1_PIN_SCL,
    GSL_I2C1_PIN_SDA};

// initialize DMA settings

// I2C1 TX --> DMA 1 stream 6 or 7 channel 1
#ifndef GSL_I2C1_DMA_TX_STREAM
#define GSL_I2C1_DMA_TX_STREAM DMA1_Stream6
#endif
#define GSL_I2C1_DMA_TX_CHANNEL DMA_CHANNEL_1

// I2C1 RX --> DMA 1 stream 0 or 5 channel 1
#ifndef GSL_I2C1_DMA_RX_STREAM
#define GSL_I2C1_DMA_RX_STREAM DMA1_Stream0
#endif
#define GSL_I2C1_DMA_RX_CHANNEL DMA_CHANNEL_1

// setup for the I2C1 DMA TX stream
DMA_HandleTypeDef gsl_i2c1_hdmatx = {
    GSL_I2C1_DMA_TX_STREAM,
    {
        GSL_I2C1_DMA_TX_CHANNEL,
        DMA_MEMORY_TO_PERIPH,
        DMA_PINC_DISABLE,
        DMA_MINC_ENABLE,
        DMA_PDATAALIGN_BYTE,
        DMA_MDATAALIGN_BYTE,
        DMA_NORMAL,
        DMA_PRIORITY_MEDIUM,
        DMA_FIFOMODE_DISABLE,
        DMA_FIFO_THRESHOLD_FULL,
        DMA_MBURST_SINGLE,
        DMA_PBURST_SINGLE},
    HAL_UNLOCKED,
    HAL_DMA_STATE_RESET,
    nullptr,
    nullptr,
    nullptr,
    nullptr,
    nullptr,
    nullptr,
    nullptr,
    HAL_DMA_ERROR_NONE,
    0,
    0};
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

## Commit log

2019-03-30 added hardware plans for simulating printer peripheral
2019-03-31 Added DMA stream assignments
2019-03-31 changed (corrected) typical thermistor value is 100K
2019-04-03 added EaglePCB project directory
    [cert3d_rev1.brd, cert3d_rev1.sch]
2019-04-03 added renders of rev1 board
    [cert3d_rev1.brd, cert3d_rev1.sch]
2019-04-03 added 2000dpi board renders
2019-04-09 updated eagle board files with part numbers
    [cert3d_rev1.brd, cert3d_rev1.sch]
2019-04-10 formatting, commented some debug print statements
2019-04-18 improvements to zoom with mouse wheel
2019-04-19 moved child thread functionality into separate class
2019-04-23 big update to add testing framework and control of printer port
2019-04-24 added thoughts on simulating hotend position
2019-04-24 close children if main frame is exited before children
2019-04-28 added C3D board firmware
2019-04-28 move C3D and printer status to status bar
2019-04-29 implemented ADC handling
2019-04-29 reworked some ASSERT_* macros to avoid warning messages
    [c3d_main.cpp]
2019-04-30 added endstop emulation
2019-10-18 add DMA monitor
2019-10-22 updates to get ADC channels working
2019-12-29 added rev2 PCB
    [cert3d_rev2.brd, cert3d_rev2.sch]
2019-12-30 added equation of motion spreadsheet
    [solving_equations_of_motion.xlsx]
2020-01-01 finalized rev2 PWB
    [cert3d_rev2.brd, cert3d_rev2_rounded.brd]
2020-01-08 work on motion planner
    [solving_equations_of_motion.xlsx]
